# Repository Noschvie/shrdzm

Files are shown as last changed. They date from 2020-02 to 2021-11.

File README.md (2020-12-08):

SHRDZM   

## SHRDZM is intended to become an end-to-end integration platform.
It provides wiring digrams, source code and working examples.
Also plug-ins for most commonly used home automation solutions will be collected.

To build cheap integrations of many kind of sensors and/or actors into your own automation solution with the focus on energy efficiancy (battery operated devices) and simpleness.

Take a look on the [Wiki](https://github.com/saghonfly/shrdzm/wiki)

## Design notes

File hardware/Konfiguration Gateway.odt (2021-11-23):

Konfiguration Gateway:

1. Resetten bei gleichzeitig gedrücktem Pairing-Knopf

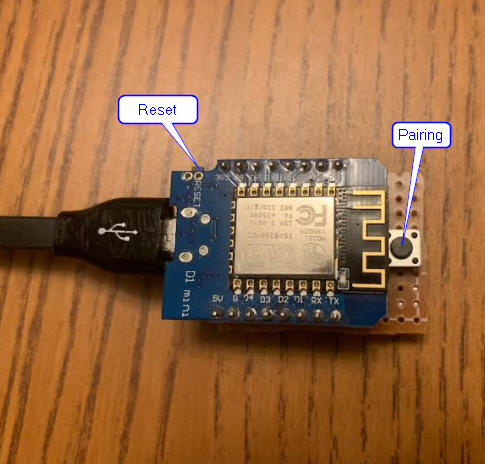
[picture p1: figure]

2. Wenn die LED vom Wemos blinkt, Pairing Knopf loslassen. Das Gateway befindet sich jetzt im AP Modus.
3. Mit dem AP verbinden

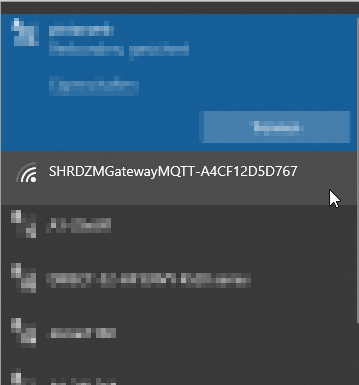
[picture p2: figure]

4. Mit dem Browser auf 192.168.4.1 gehen

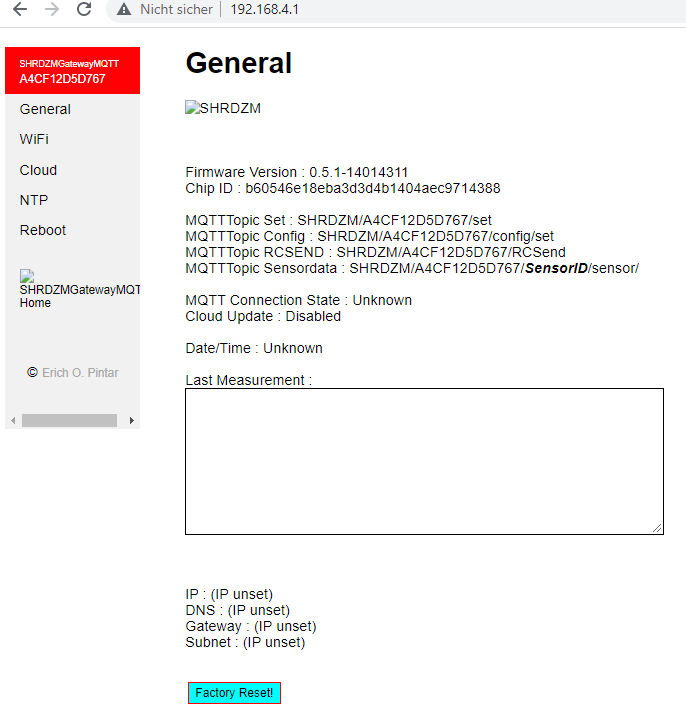
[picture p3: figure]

5. Auf WiFi Einstellungen gehen und die Zugangsdaten vom Router eingeben.

Zum Testen die MQTT Einstellungen auf test.msoquitto.org lassen. Für den produktiven Betrieb wird aber dringend ein eigener MQTT Broker empfohlen!

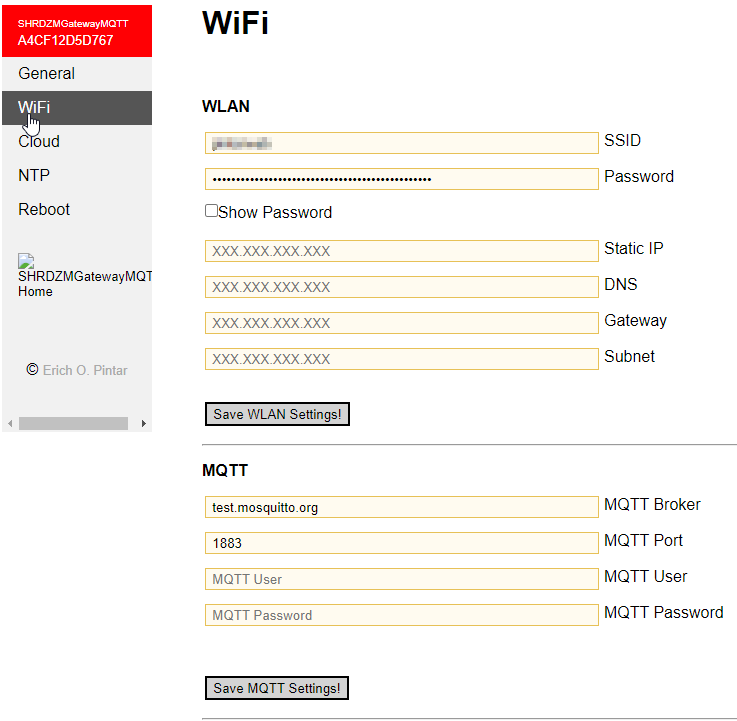
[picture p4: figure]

6. Gateway booten. Dieses sollte sich nun in das eigene WLAN eingebucht haben bzw. eine eigene IP Adresse von diesem bekommen haben über die das Gateway wieder erreichbar sein sollte.
7. Einen MQTT Client starten. Ich empfehle MQTT.fx (nicht die aktuellste Version, die ist mittlerweile kostenpflichtig, eine Ältere tuts auch)

Einstellungen für test.mosquitto.org

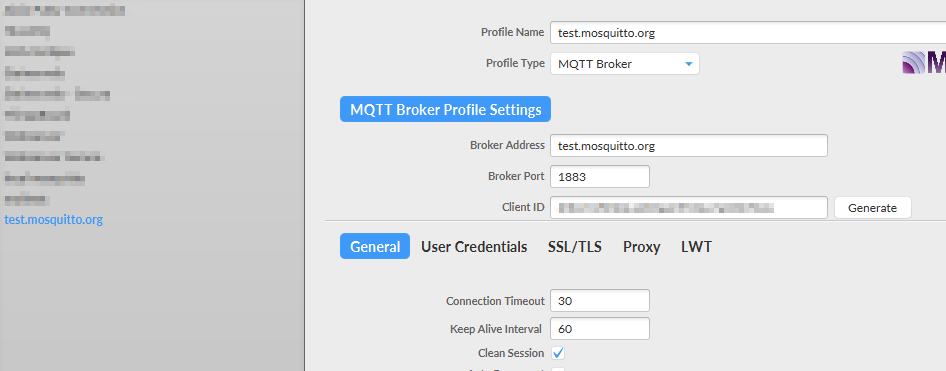
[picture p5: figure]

8. Mit test.mosquitto.org verbinden und für ‚SHRDZM/#‘ Nachrichten registrieren

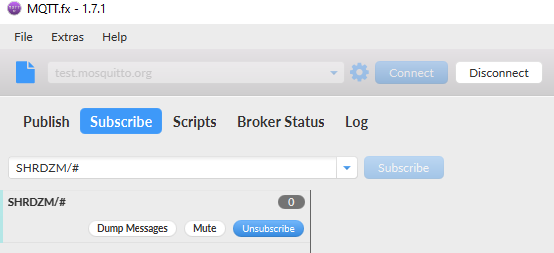
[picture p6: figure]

9. Gateway booten. Sobald das Gateway gebootet hat, sollten schon ein paar Nachrichten sichtbar sein.

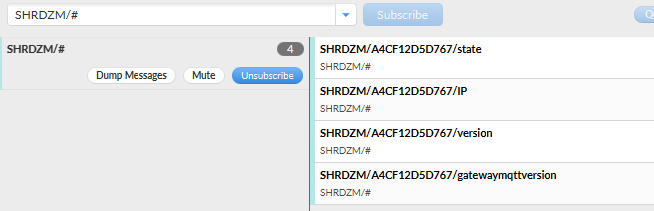
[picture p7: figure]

10. Auf den Reiter Publish gehen und den eigenen Cipherkey (32 Zeichen) an das Gateway schicken

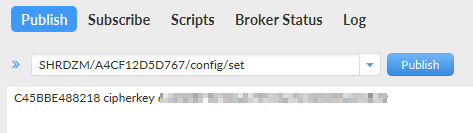
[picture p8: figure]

^

11. Der Cipherkey wird übernommen sobald der Sensor aufwacht (kann bis zu 2 Minuten dauern) bzw. der Accu neu eingelegt wird.
12. Sensor beim SmartMeter anstecken. Ab jetzt sollten alle 2 Minuten decodierte Messwerte ankommen

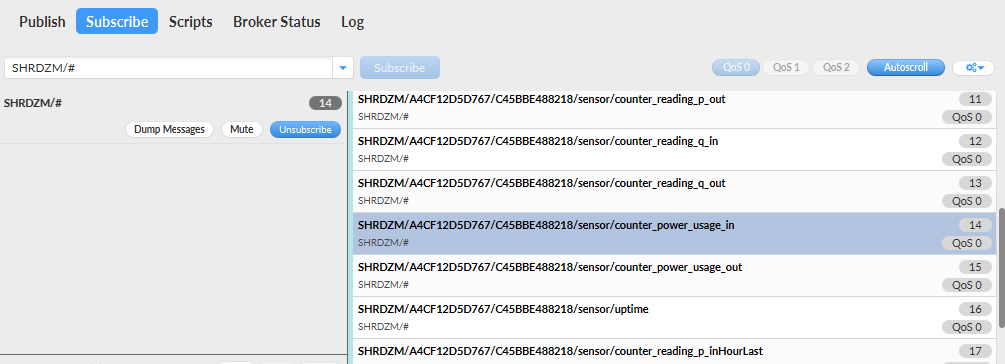
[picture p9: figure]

Die Werte für uptime, counter_reading_p_inHourLast und counter_reading_p_inDayLast können bei der batteriebetriebenen Variante ignoriert werden. Diese stimmen nur bei Sensoren die permanent mit Strom versorgt werden.

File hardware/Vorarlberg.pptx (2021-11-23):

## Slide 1

- KSMWest H1 interface

- Electricity Metering Solutions

- KSMWest

- 08.05.2018

## Overview M-Bus - Physical Layer

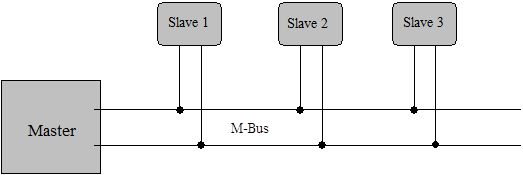
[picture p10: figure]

The M-Bus consists of
- The master,
- A number of slaves
- A two-wire connecting cable

Master to Slave => The transfer of bits from master to slave is accomplished by means of voltage level shifts.
- A logical "1" (Mark) corresponds to a nominal voltage of +36 V
- A logical "0" (Space) reduces the bus voltage by 12 V to a nominal +24 V
Slave to Master => The transfer of bits from slave to master slave is accomplished by means of modulating the current consumption of the slave.
- A logical "1" (Mark) is represented by a constant current of up to 1.5 mA,
- A logical "0" (Space) is represented by an increased current drain requirement by the slave of additional 11-20 mA.

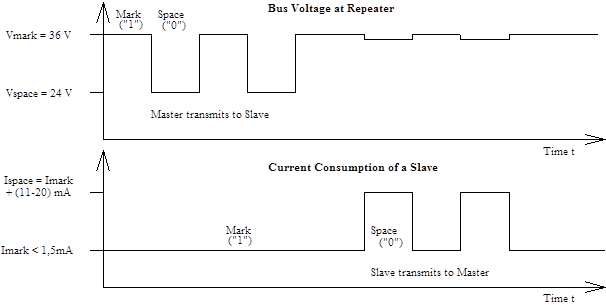
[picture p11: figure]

## Overview M-Bus - Data Link Layer

Telegram format - FT 1.2 according to IEC 870-5:
=> The format class FT 1.2 specifies three different telegram formats, which can be recognized by means of special start characters
Single Character
This format consists of a single character, namely the E5h (decimal 229), and serves to acknowledge receipt of transmissions.
Short Frame
This format with a fixed length begins with the start character 10h, and besides the C and A fields includes the check sum (this is made up from the two last mentioned characters), and the stop character 16h.
Long Frame
With the long frame, after the start character 68h, the length field (L field) is first transmitted twice, followed by the start character once again. After this, there follow the function field (C field), the address field (A field) and the control information field (CI field). The L field gives the quantity of the user data inputs plus 3 (for C,A,CI). After the user data inputs, the check sum is transmitted, which is built up over the same area as the length field, and in conclusion the stop character 16h is transmitted.
Control Frame
The control sentence conforms to the long sentence without user data, with an L field from the contents of 3. The check sum is calculated at this point from the fields C, A and CI.

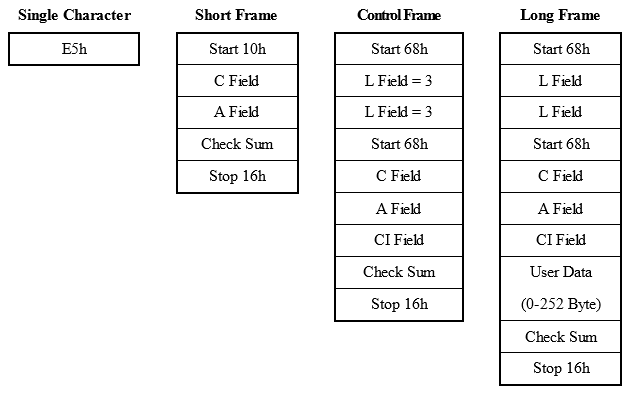
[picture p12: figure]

## Overview M-Bus - Data Link Layer

C Field (Control Field)
The control field specifies the direction of data flow, and is responsible for various additional tasks in both the calling and replying directions.
A Field (Address Field)
The address field serves to address the recipient in the calling direction, and to identify the sender of information in the receiving direction. The size of this field is one Byte, and can therefore take values from 0 to 255.
- Address 0: indicates an unconfigured slave
- Address 1-250: can be allocated to the individual slaves
- Address 251-252: reserved
- Address 253: Network Layer addressing used instead of Data Link Layer addressing
- Address 254: broadcast - all slaves reply with their own addresses
- Address 255: broadcast - none of the slaves reply
CI Field (control information field)
The control information field is already a part of the Application Layer, The control information allows the implementation of a variety of actions in the master or the slaves.
Check Sum
The Check Sum is calculated from the arithmetical sum of the data mentioned above, without taking carry digits into account.

Coding of the Control Field

Control Codes of the M-Bus Protocol (F : FCB-Bit, A : ACD-Bit, D : DFC-Bit)

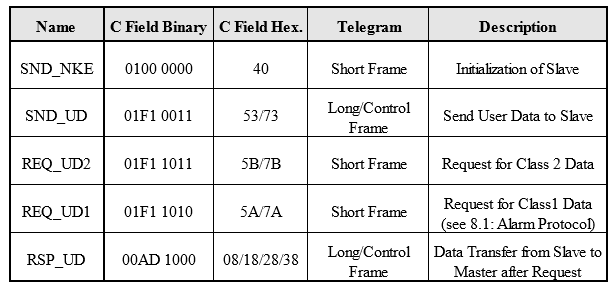
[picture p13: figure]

## Overview M-Bus – Transport Layer

CI field values

The M-Bus transport layer allows several application layers to co-exist over the M-Bus lower layers.
These may be:
- the M-Bus dedicated AL
- the DLMS/COSEM AL
- some other AL that may be specified in the future.
The AL used is selected by the Control Information (CI) field of the M-Bus frame.

CI | Application
00h-1Fh | DLMS/COSEM M-Bus based TL No M-Bus Data Header is present
20h-4Fh | reserved for DLMS-based applications
50h | application reset
51h | data send (master to slave)
52h | selection of slaves
53h | reserved
54h-58h | reserved for DLMS-based applications
55h-5Bh | reserved
5Ch | synchronise action
60h | DLMS/COSEM M-Bus based TL Long M-Bus Data Header present, direction master to slave
61h | DLMS/COSEM M-Bus based TL Short M-Bus Data Header present, direction master to slave
62h-6Fh | reserved
70h | slave to master: report of application errors
71h | slave to master: report of alarms
72h | slave to master: 12 byte header followed by variable format data
73h-77h | reserved
78h | slave to master: Variable data format response without header
79h | reserved
7Ah | slave to master: 4 byte header followed by Variable data format response
7Bh | reserved
7Ch | DLMS/COSEM M-Bus based TL Long M-Bus Data Header present, direction slave to master
7Dh | DLMS/COSEM M-Bus based TL Short M-Bus Data Header present, direction slave to master
7Eh-80h | reserved
81h | Reserved for a future CEN-TC294- Radio relaying and application Layer
82h | Reserved for a future CENELEC-TC205 network/application Layer
82h-8Fh | reserved
90h-97h | manufacturer specific (obsolete)
A0h-AFh | manufacturer specific
B0-B7h | manufacturer specific
B8h | set baudrate to 300 baud
B9h | set baudrate to 600 baud
BAh | set baudrate to 1200 baud
BBh | set baudrate to 2400 baud
BCh | set baudrate to 4800 baud
BDh | set baudrate to 9600 baud
BEh | set baudrate to 19200 baud
BFh | set baudrate to 38400 baud
C0h-FFh | reserved

## DLMS/COSEM M-Bus transport layer

DLMS/COSEM AL based CI values

CI without M-Bus Data Header

The values CITL = 0x00…0x1F indicate that no M-Bus Data Header is present. In this case, the TL can provide segmentation and reassembly
- Bit 4 (FIN) indicates that the Data field of the TPDU carries either one part of an xDLMS APDU or the complete APDU.
- Bits 3 to 0 are used for sequence numbering. The rollover of the sequence numbers is permitted, meaning that when the sequence number reaches the value 1111 and there are segments remaining to be sent, the next segment sequence number will take the value 0000.

## Example M-Bus frame

## Example M-Bus frame

DLMS/COSEM APDU

DLMS/COSEM APDU (decrypted payload)

data-notification
long-invoke-id-and-priority
invoke-id: 366
not-self-descriptive
processing-option: continue on error
service-class: unconfirmed
priority: normal
date-time
07 E0 09 09 05 11 3A 00 00 FF C4 80 '......:.....'
2016/09/09 17:58:00
Day of Week: 5
Deviation to GMT: -60 minutes
Clock Status: 80
notification-body
data
structure with 7 elements
struct-element-0
octet-string:
07 E0 09 09 05 11 3A 00 00 00 00 80 '......:.....'
struct-element-1
octet-string:
01 00 01 08 00 FF '......'
struct-element-2
double-long-unsigned: 0
struct-element-3
structure with 2 elements
struct-element-0
integer: 0
struct-element-1
enum: 30
struct-element-4
octet-string:
01 00 03 08 00 FF '......'
struct-element-5
double-long-unsigned: 0
struct-element-6
structure with 2 elements
struct-element-0
integer: 0
struct-element-1
enum: 32

general-glo-ciphering
45 4C 53 65 70 00 00 01 'ELSep...'
system-title: 454c536570000001
ciphered-service:
length: 77
security-control-byte
security-suite-id: 0
encryption
key-set: unicast
frame-counter: 144
apdu:
E2 A3 30 F9 B7 E0 D6 8C 09 37 5A A1 B1 F8 F3 A7 '..0......7Z.....'
DF 14 B7 79 0E 14 D1 55 6A B8 75 B1 49 E6 84 7D '...y...Uj.u.I..}'
11 93 6D B5 19 1D D0 F4 89 BA 76 8C 2D BB 68 F6 '..m.......v.-.h.'
B0 01 E3 04 C2 1F EA 14 7E 0B 2E 2C A1 B9 1D 57 '........~..,...W'
4D F4 F7 F5 82 CE BE 92 'M.......'

## Companion Standard – H1 interface

## Thank you!

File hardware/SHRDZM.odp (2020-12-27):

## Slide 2

SHRDZMDevice

SHRDZMDevice

SHRDZMDevice

SHRDZMDevice

SHRDZMDevice

SHRDZMGateway

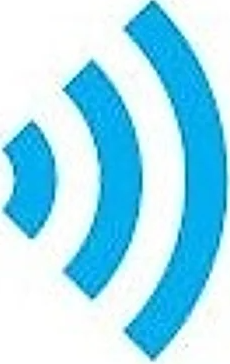
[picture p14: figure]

SHRDZMGatewayMQTT

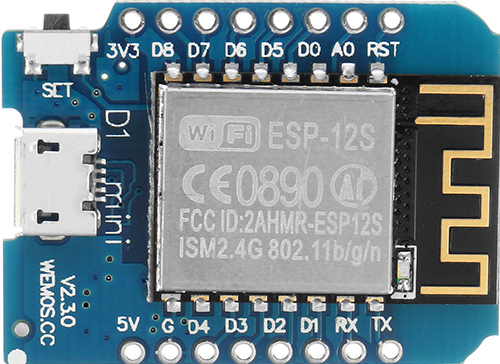
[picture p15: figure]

Home Automation
Solution

WLAN

SERIAL

ESPNow

Sensor
Actor

Sensor
Actor

Sensor
Actor

Sensor
Actor

Sensor
Actor

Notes: Copyright © Infineon Technologies AG 2020. All rights reserved. restricted 2020-05-25 <Nummer>

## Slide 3

SHRDZMDevice

SHRDZMDevice

SHRDZMDevice

SHRDZMDevice

SHRDZMDevice

SHRDZMGateway

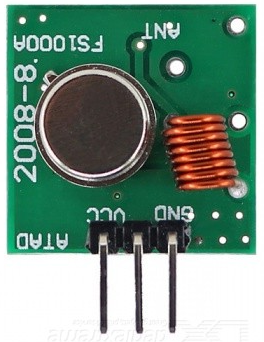
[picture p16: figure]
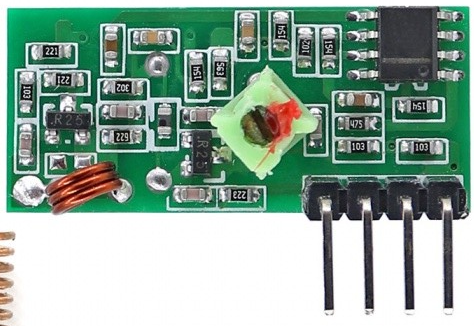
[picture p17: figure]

433MHz Transmitter/Receiver

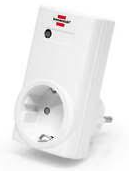
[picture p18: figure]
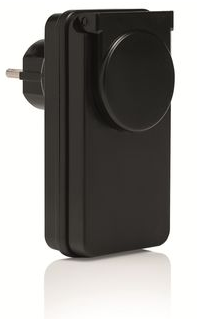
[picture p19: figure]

SHRDZMGatewayMQTT

Home Automation
Solution

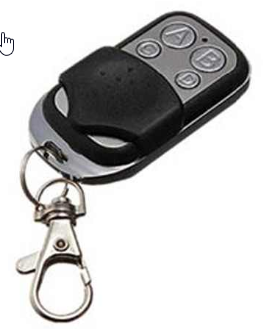
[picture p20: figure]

WLAN

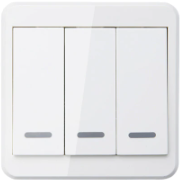
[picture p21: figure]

SERIAL

ESPNow

Sensor
Actor

Sensor
Actor

Sensor
Actor

Sensor
Actor

Sensor
Actor

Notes: Copyright © Infineon Technologies AG 2020. All rights reserved. restricted 2020-05-25 <Nummer>

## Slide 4

SHRDZMDevice

SHRDZMDevice

SHRDZMDevice

SHRDZMDevice

SHRDZMDevice

SHRDZMGateway

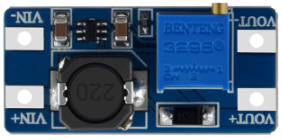
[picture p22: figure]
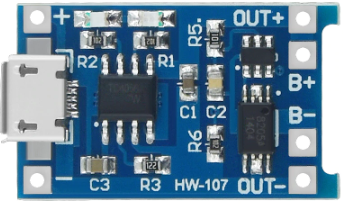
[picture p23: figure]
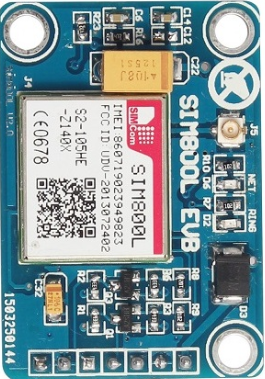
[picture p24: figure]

Home Automation
Solution

GSM

3.7V

5V

SERIAL

5V - USB

3.7V

3.7V

ESPNow

Sensor
Actor

Sensor
Actor

Sensor
Actor

Sensor
Actor

Sensor
Actor

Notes: Copyright © Infineon Technologies AG 2020. All rights reserved. restricted 2020-05-25 <Nummer>

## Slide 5

SHRDZMDevice

SHRDZMDevice

SHRDZMDevice

SHRDZMDevice

SHRDZMDevice

SHRDZMGatewayMobile


Home Automation
Solution

GSM

SERIAL

ESPNow

Sensor
Actor

Sensor
Actor

Sensor
Actor

Sensor
Actor

Sensor
Actor

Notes: Copyright © Infineon Technologies AG 2020. All rights reserved. restricted 2020-05-25 <Nummer>

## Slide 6

5 Volt

SHRDZMDevice

Home Automation
Solution

WLAN

Sensor
Actor

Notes: Copyright © Infineon Technologies AG 2020. All rights reserved. restricted 2020-05-25 <Nummer>


5 Volt/ >= 500mA

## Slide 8


Replace existing capacitor with 2200uF

5 Volt - USB


+5V

Optional


Solar Panel
~5 Watt

+

AccessPoint
Trigger

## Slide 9

5 Volt - USB


Optional

Solar Panel
~5 Watt

AccessPoint
Trigger

+

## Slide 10

S

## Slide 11

Boot

Pairing Pin

Closed

Normal Mode

> 5 sec

Pairing Mode

0 sec

Pairing Pin

Closed

> 3 sec, < 10 sec

Configuration AP Mode

Pairing Pin

Closed

Factory Reset

> 10 sec

FHEM Server


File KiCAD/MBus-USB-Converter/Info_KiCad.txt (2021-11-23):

Application: kicad
Version: (5.0.1)-4, release build
Libraries:
    wxWidgets 3.0.4
    libcurl/7.61.1 OpenSSL/1.1.1 (WinSSL) zlib/1.2.11 brotli/1.0.6 libidn2/2.0.5 libpsl/0.20.2 (+libidn2/2.0.5) nghttp2/1.34.0
Platform: Windows 7 (build 7601, Service Pack 1), 64-bit edition, 64 bit, Little endian, wxMSW

Build Info:
    wxWidgets: 3.0.4 (wchar_t,wx containers,compatible with 2.8)
    Boost: 1.68.0
    OpenCASCADE Community Edition: 6.9.1
    Curl: 7.61.1
    Compiler: GCC 7.3.0 with C++ ABI 1011

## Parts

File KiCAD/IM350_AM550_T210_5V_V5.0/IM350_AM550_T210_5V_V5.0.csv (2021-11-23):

Comment | Designator | Footprint | LCSC
22uF | C1,C2,C4 | Capacitor_SMD:C_1206_3216Metric_Pad1.33x1.80mm_HandSolder
0.1uF | C3 | Capacitor_SMD:C_1206_3216Metric_Pad1.33x1.80mm_HandSolder
0.22uF | C5 | Capacitor_SMD:C_1206_3216Metric_Pad1.33x1.80mm_HandSolder
USB_B_Micro_Power | J1 | SHRDZM:USB_Micro-B_Power
RJ12 | J2 | ErichCollection:RJ12_Amphenol_54601
BC847 | Q1 | Package_TO_SOT_SMD:SOT-23
P3 | R1 | Resistor_SMD:R_0201_0603Metric_Pad0.64x0.40mm_HandSolder
1.5k | R5,R10 | Resistor_SMD:R_0805_2012Metric_Pad1.20x1.40mm_HandSolder
220 | R11,R12 | Resistor_SMD:R_0805_2012Metric_Pad1.20x1.40mm_HandSolder
0 | R13 | Resistor_SMD:R_0201_0603Metric_Pad0.64x0.40mm_HandSolder
30k | R15 | Resistor_SMD:R_0805_2012Metric_Pad1.20x1.40mm_HandSolder
M_RX | R18 | Resistor_SMD:R_0201_0603Metric_Pad0.64x0.40mm_HandSolder
P4 | R2 | Resistor_SMD:R_0201_0603Metric_Pad0.64x0.40mm_HandSolder
2.2k | R3 | Resistor_SMD:R_0805_2012Metric_Pad1.20x1.40mm_HandSolder
100k | R4,R14 | Resistor_SMD:R_0805_2012Metric_Pad1.20x1.40mm_HandSolder
M_TX | R6 | Resistor_SMD:R_0201_0603Metric_Pad0.64x0.40mm_HandSolder
P1_TX | R7 | Resistor_SMD:R_0201_0603Metric_Pad0.64x0.40mm_HandSolder
10k | R8,R9,R16,R17 | Resistor_SMD:R_0805_2012Metric_Pad1.20x1.40mm_HandSolder
SW_Push | SW1 | Button_Switch_SMD:SW_SPST_CK_RS282G05A3
AMS1117-3.3 | U1 | Package_TO_SOT_SMD:SOT-223-3_TabPin2
ESP-12F | U2 | RF_Module:ESP-12E
TSS721ADR | U3 | TSS721ADR:SOIC127P600X175-16N
EL357NC | U4,U5 | Package_SO:SOIC-4_4.55x2.6mm_P1.27mm

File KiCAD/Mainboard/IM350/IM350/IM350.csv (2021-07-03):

Comment | Designator | Footprint | LCSC
22uF | C1,C2 | 603 | C59461
USB_B_Micro | J1 | Connector_USB:USB_Micro-B_GCT_USB3076-30-A
Conn_02x03_Odd_Even | J2 | Connector_PinHeader_2.54mm:PinHeader_2x03_P2.54mm_Horizontal
BC547 | Q1 | Package_TO_SOT_THT:TO-92_Inline_Horizontal1
10k | R1,R2,R3 | 402 | C25744
SW_Push | SW1 | Button_Switch_THT:SW_PUSH_6mm
AMS1117-3.3 | U1 | SOT-223 | C6186
ESP-12F | U2 | RF_Module:ESP-12E

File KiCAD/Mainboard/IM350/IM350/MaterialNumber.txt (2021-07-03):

10kOhm 		0402 		C25744
AMS1117 	SOT-223 	C6186
22uF		0603		C59461

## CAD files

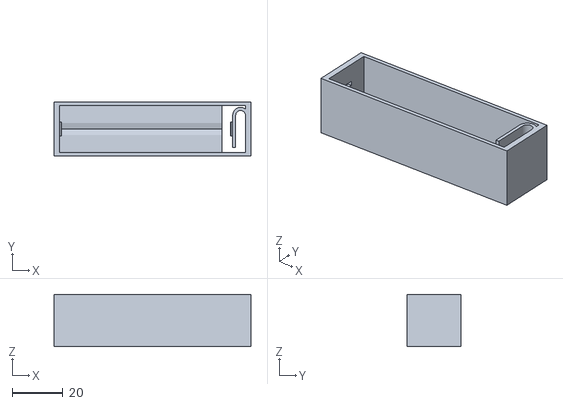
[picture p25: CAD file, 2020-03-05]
3d/18650/Bottom.stl
77.4 x 21.4 x 20.6

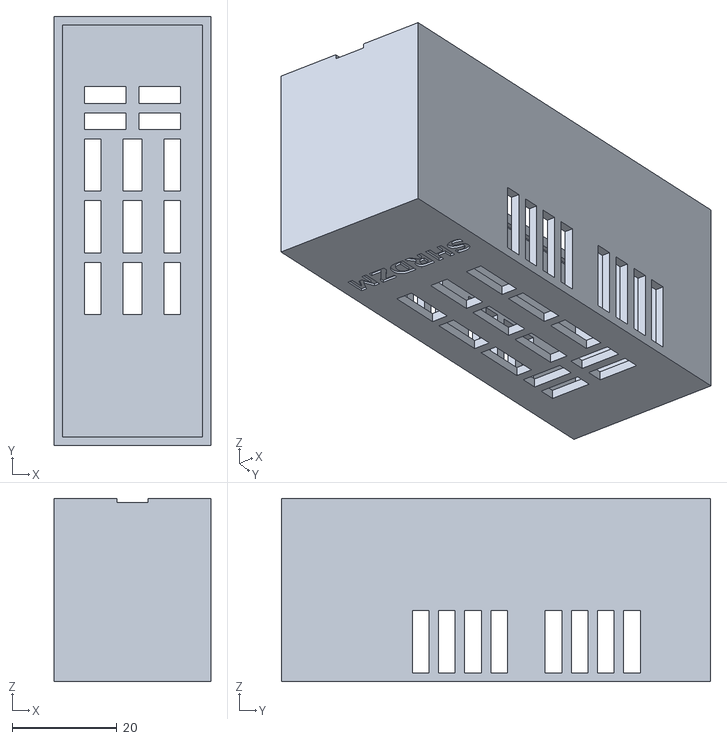
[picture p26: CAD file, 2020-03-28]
3d/Case2.stl
30.0 x 82.0 x 35.0

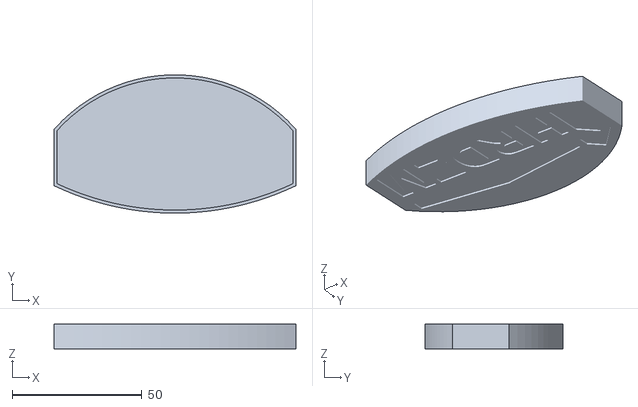
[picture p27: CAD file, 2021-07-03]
3d/Watersensor/HolderTop_2.stl
93.4 x 53.3 x 9.50

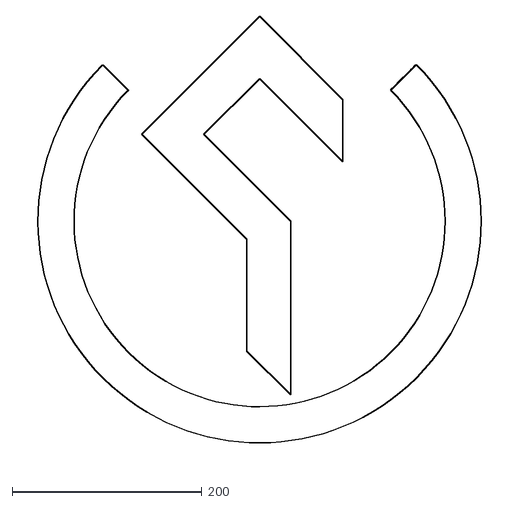
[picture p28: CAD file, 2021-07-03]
hardware/Logo_min.dxf
512.7 x 472.1

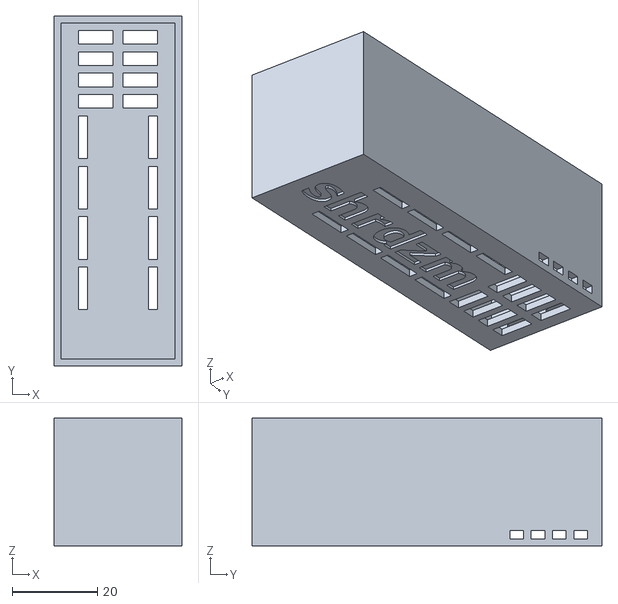
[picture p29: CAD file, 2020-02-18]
3d/Case1.stl
30.0 x 82.0 x 30.0

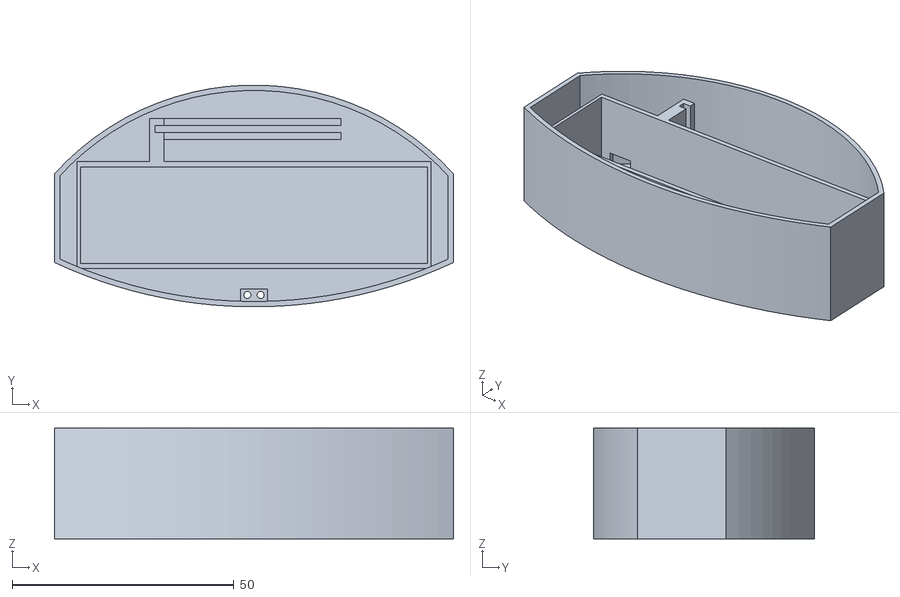
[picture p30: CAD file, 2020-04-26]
3d/Watersensor/Holder_1.stl
90.0 x 49.9 x 25.0

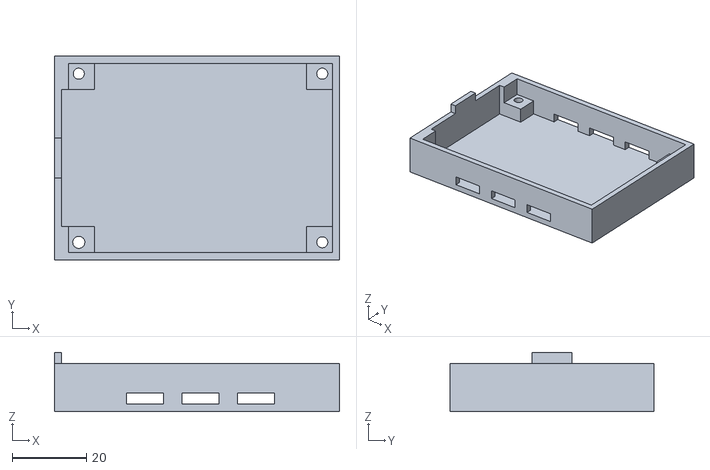
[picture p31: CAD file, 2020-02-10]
hardware/ESPWLANGatewayBottom.stl
76.9 x 55.0 x 16.0

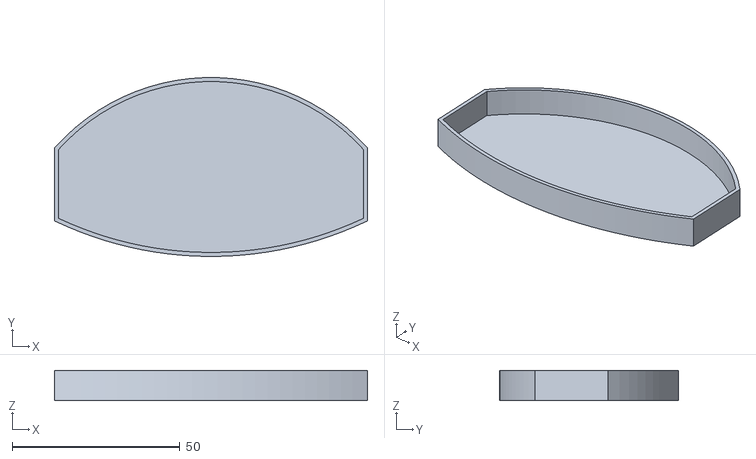
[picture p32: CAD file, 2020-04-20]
3d/Watersensor/HolderTop_1.stl
93.4 x 53.3 x 9.00

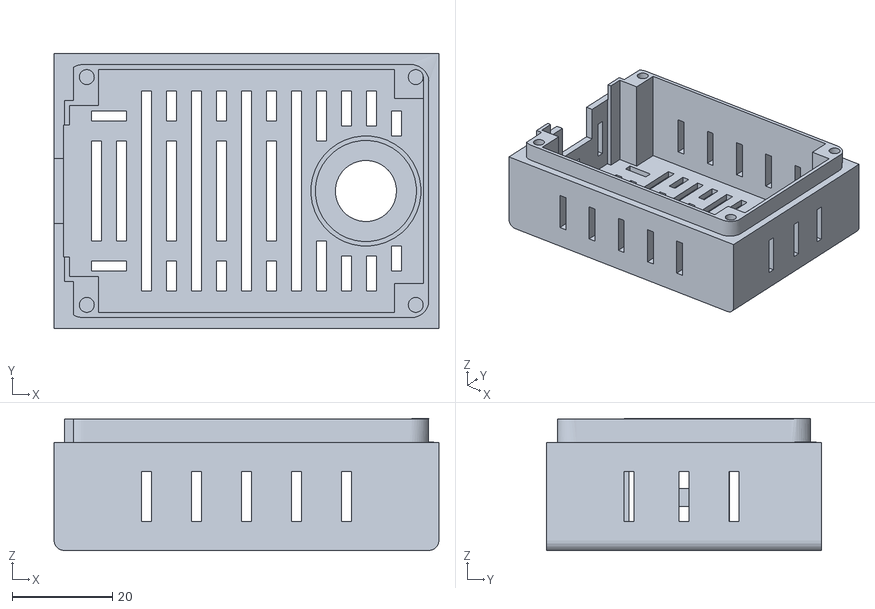
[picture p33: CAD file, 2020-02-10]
hardware/ESPWLANGatewayTop.stl
76.9 x 55.0 x 26.4

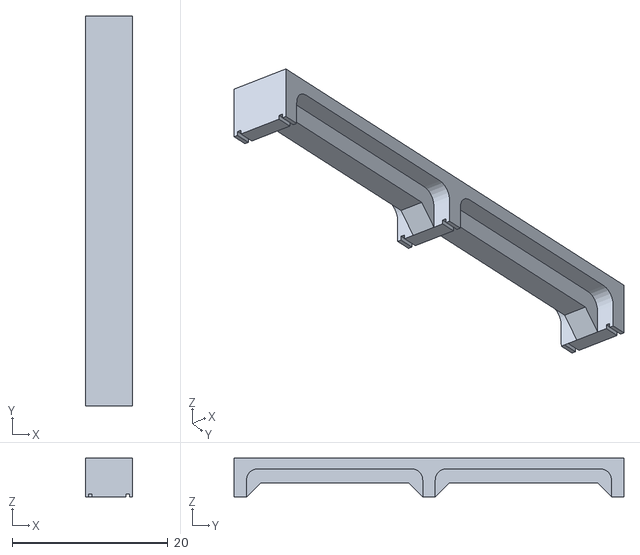
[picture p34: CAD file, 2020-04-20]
3d/Watersensor/Holder.stl
6.00 x 50.0 x 5.00

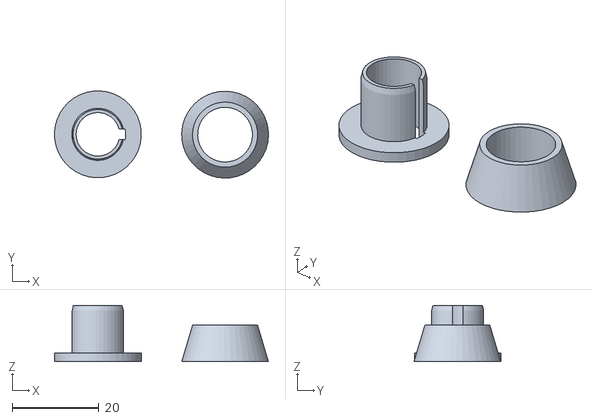
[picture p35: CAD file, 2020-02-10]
hardware/ESPWLANGatewayAntennaHolder.stl
49.3 x 20.1 x 13.0

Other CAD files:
3d/18650/Bottom.skp
3d/18650/Bottom1.skp
3d/18650/Bottom2.skp
3d/Case1.skp
3d/Case2-0.skp
3d/Case2.skp
3d/Watersensor/Holder.skp
3d/Watersensor/HolderTop_1.skp
3d/Watersensor/HolderTop_2.skp
3d/Watersensor/Holder_1-0.skp
3d/Watersensor/Holder_1.skp

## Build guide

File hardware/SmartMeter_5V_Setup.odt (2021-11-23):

SHRDZMDevice für SmartMeter

Einstellungen

1) Pairing-Knopf gedrückt halten und 5V Stromversorgung (mindestens 1A) anstecken.

2) Paining-Knopf loslassen. Die blaue LED blinkt ca. alle halbe Sekunde auf. Das Device befindet sich nun im Pairing-Modus mit einem optionalen Gateway (für Batteriebetrieb, hier nicht der Fall!)
3) Mindesten 5 Sekunden warten und Pairing-Knopf erneut für ca. 5 Sekunden gedrückt halten. Loslassen sobald die blaue LED schnell zu blinken beginnt. Nun befindet sich das Device im AccessPoint Modus.

4) Sobald sich das Device im AP Modus befindet, kann mit diesem eine WLAN Verbindung aufgebaut werden:

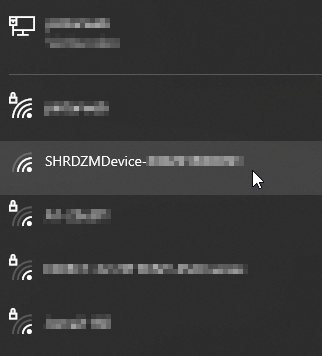
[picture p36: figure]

5) Sobald die Verbindung aufgebaut ist, kann mittels Browser über die IP-Adresse 192.168.4.1 darauf zugegriffen werden:

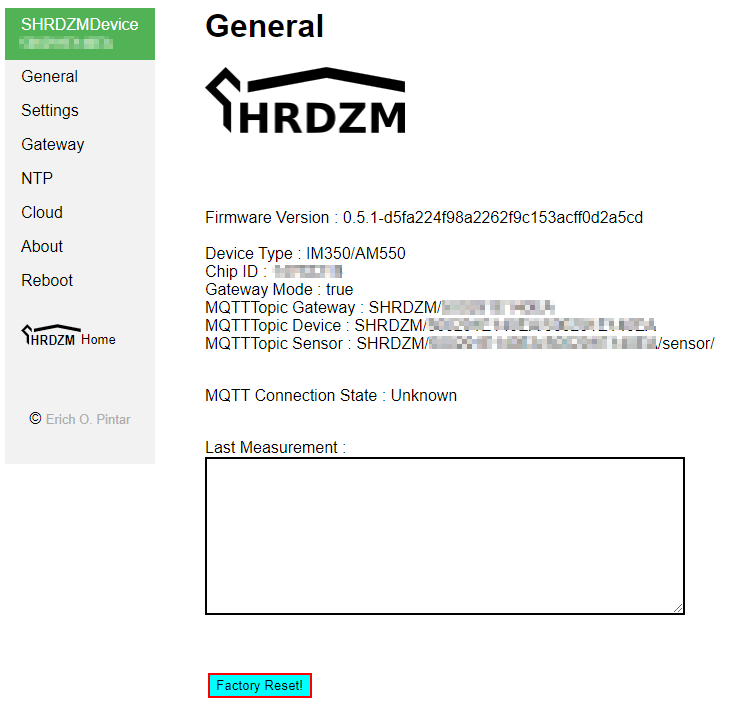
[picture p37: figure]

6) Auf Settings wechseln und den 32 Zeichen langen persönlichen Cipherkey vom Stromnetzbetreiber eintragen. Die anderen Einstellungen nicht ändern.

7) Save Configuration! drücken.

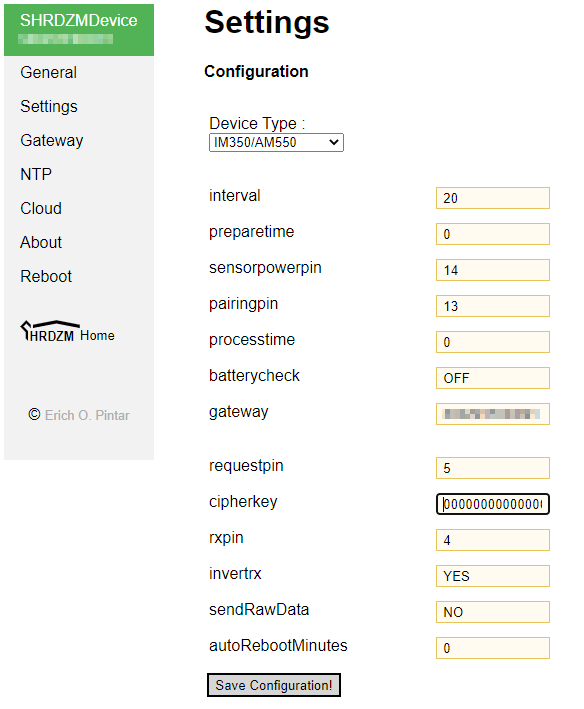
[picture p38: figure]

8) Auf Gateway Einstellungen wechseln. Hier die WiFi SSID und das Passwort eintragen.

8a) [optional] Bei Benutzung einer statischen IP, könnte auch diese eingetragen werden. Im Normalfall leer lassen da diese vom Router vergeben wird.

9) MQTT Server, Port und eventuell User und Passwort eintragen. Wenn kein User/Passwort verwendet wird, diesen leer lassen.

9a) [optional] Sollte keine Integration in die eigene Hausautomatisierung gewünscht sein, kann das Häkchen bei ‚MQTT Enable‘ entfernt werden. In solch einem Fall werden dann keine Daten an den MQTT Broker geschickt. (sinnvoll, wenn nur Cloud/Alexa Anbindung gewünscht)

10) Save Configuration! drücken.

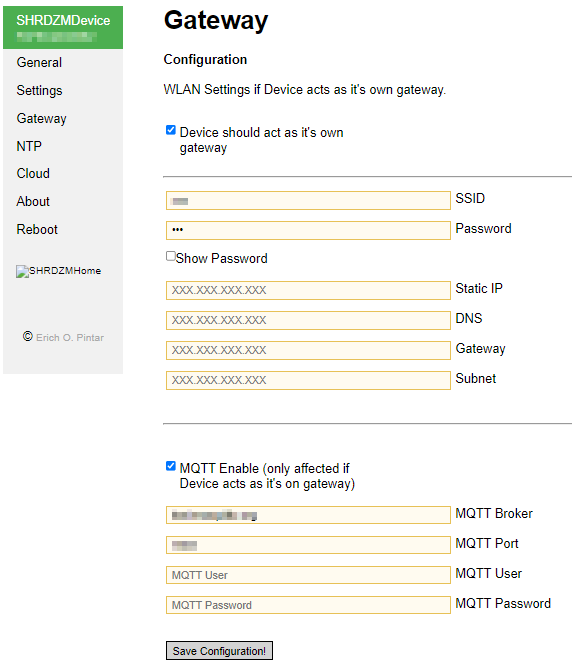
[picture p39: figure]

11) Device booten.

12) Nach dem Rebooten sollte sich das Device im WLAN einwählen und von dort eine eigene IP – Adresse bekommen. Über diese IP-Adresse ist das Device dann wieder mittels Browser erreichbar und Einstellungen können verändert werden.

13) Nach dem Verbinden mit dem SmartMeter sollten die Messwerte über die auf der Übersichtsseite beschriebenen MQTT Subjects angezeigt werden.

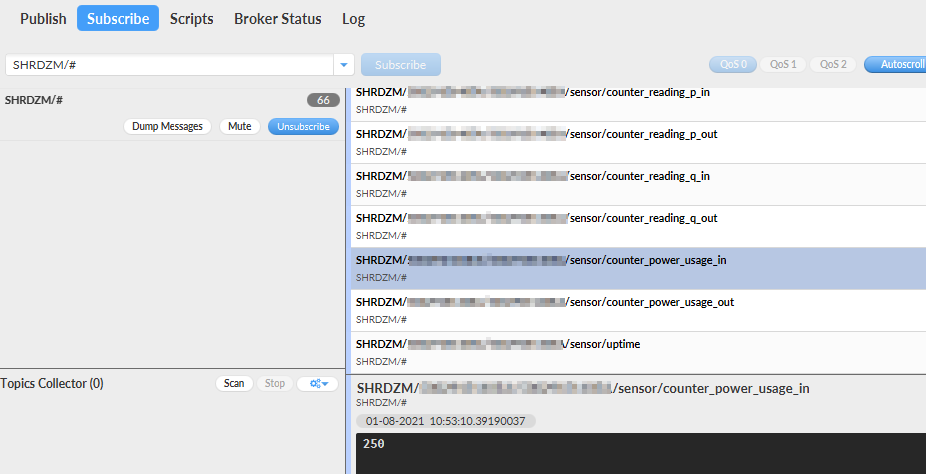
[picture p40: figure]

Optional

Das Device hat eine optionale Cloud-Anbindung die sich jedoch noch in Entwicklung befindet.

Derzeit implementiert ist nur die Alexa Anbindung. (Ein Änderung der Einstellung wirkt nicht wenn sich das Device beim Konfigurieren im AP Modus befindet!)

14) Auf Cloud Einstellungen wechseln.

15) „Cloud Enabled“ Checkbox anklicken.

16) ‚Save Cloud Settings“ drücken.

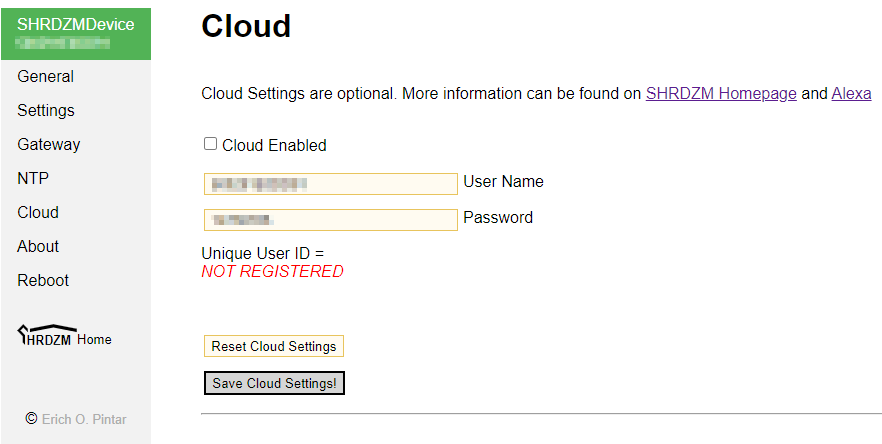
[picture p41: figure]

Der abgebildete User Name und das Passwort ist beim Alexa Account Linking zu verwenden.

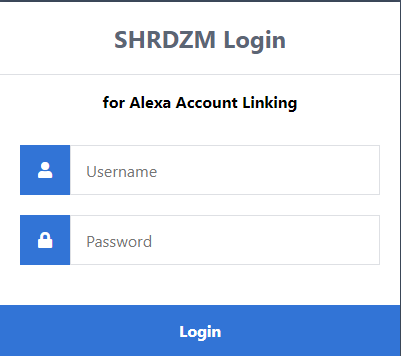
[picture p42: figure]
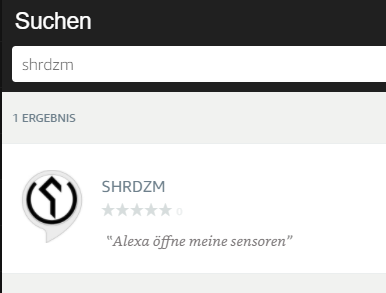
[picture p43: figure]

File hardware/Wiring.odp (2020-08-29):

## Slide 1

10 kOhm

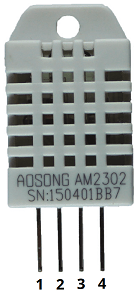
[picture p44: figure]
DHT22 Temperature and Humidity Sensor using Arduino IDE

3.3 V

+

Pairing

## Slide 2

5V USB

10 kOhm

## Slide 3

18650

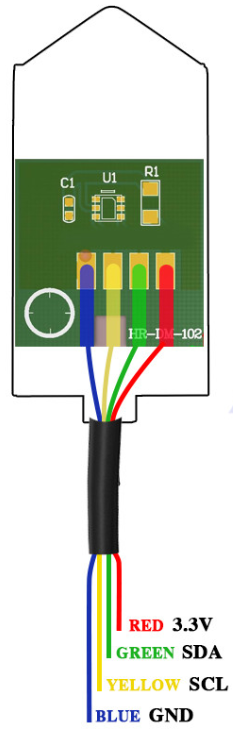
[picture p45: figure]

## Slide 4

5V USB

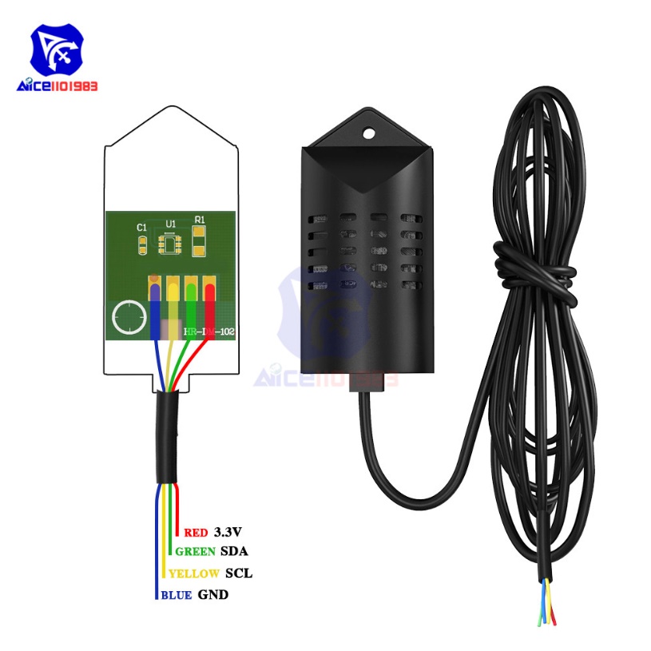
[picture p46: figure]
X12962解说图

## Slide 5

3.3 V

Pairing

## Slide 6

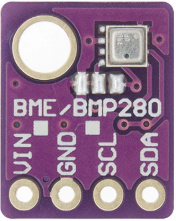
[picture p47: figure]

3.3 V

Pairing

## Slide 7

5V USB

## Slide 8

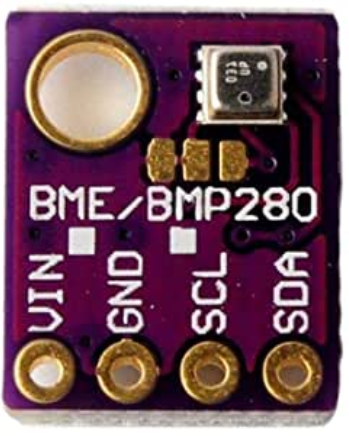
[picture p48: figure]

3.3 V

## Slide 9

5V USB

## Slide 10

GY-302

3.3 V

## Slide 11

5V USB

GY-302

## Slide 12

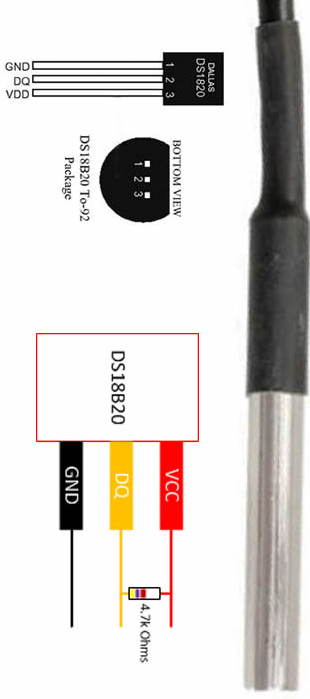
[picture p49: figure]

DS18B20

3.3 V

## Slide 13

5V USB

DS18B20

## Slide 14

18650

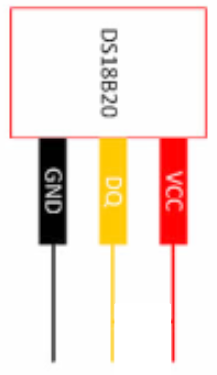
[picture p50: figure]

4,7 kΩ

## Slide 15

1 MOhm

100 nF

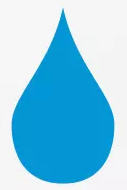
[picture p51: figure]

+

3.3 V

Pairing

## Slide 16

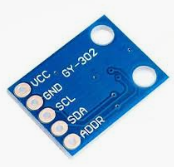
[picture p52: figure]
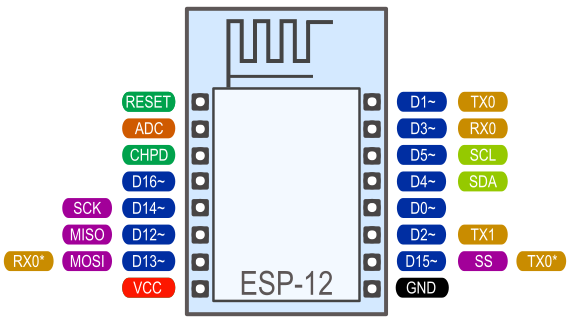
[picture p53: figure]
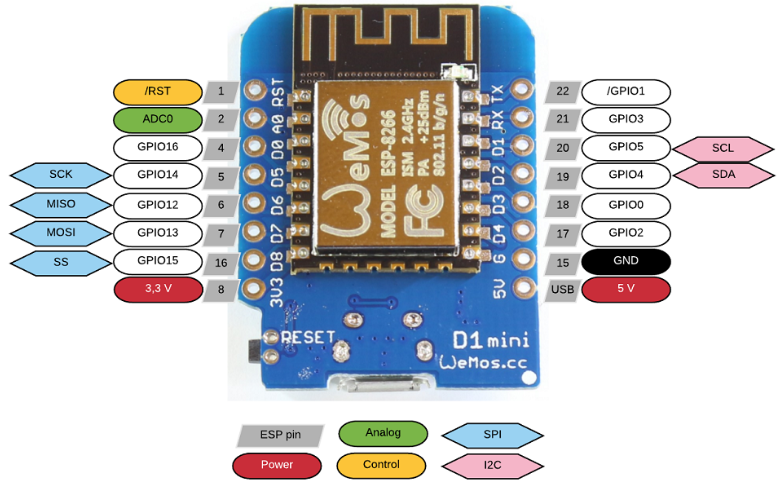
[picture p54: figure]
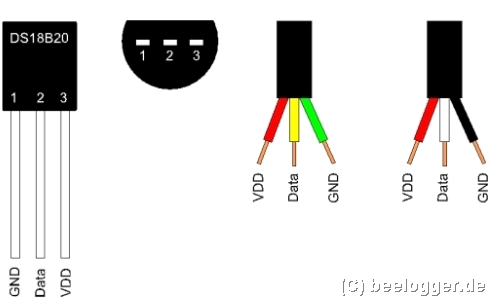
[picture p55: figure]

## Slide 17

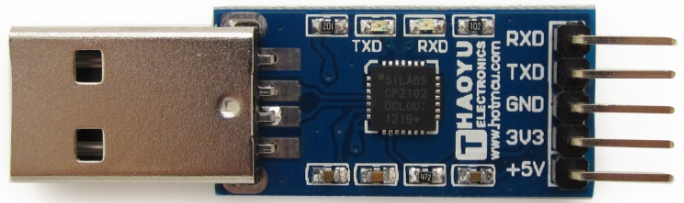
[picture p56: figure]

5V USB

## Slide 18

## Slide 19

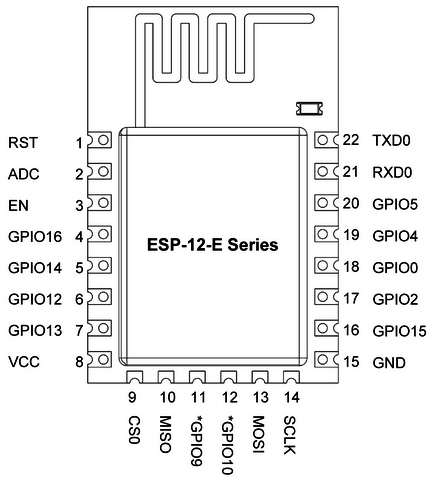
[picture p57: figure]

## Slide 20

R2

22 kOhm

R1

4.7 kOhm

R3

10 kOhm

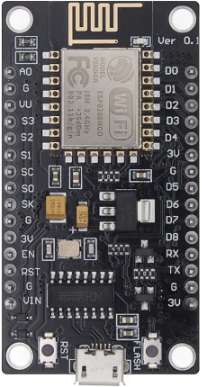
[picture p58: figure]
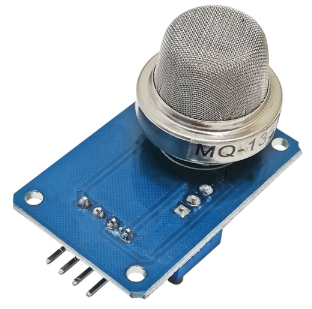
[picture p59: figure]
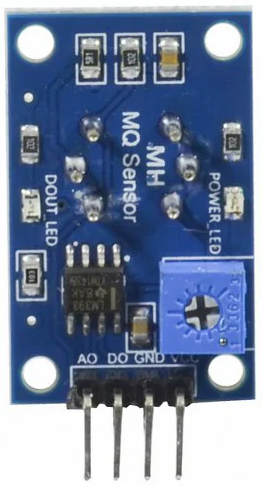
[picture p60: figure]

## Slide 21

R2

22 kOhm

R1

4.7 kOhm

R3

10 kOhm

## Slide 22

Vin

Vout

R3
10 kOhm

R1
10 kOhm

R2
3.3 kOhm

18650

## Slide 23

R3
10 kOhm

IRLZ44N

SDS011

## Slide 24

R3
10 kOhm

IRLZ44N

SDS011

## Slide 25

10kOhm

18650

100kO

330kO

5 Watt

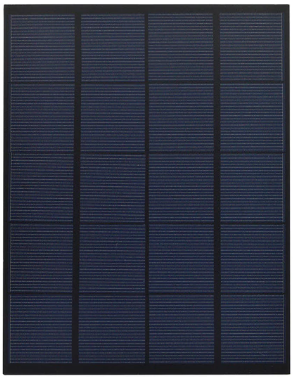
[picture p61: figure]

IRLZ44N

SDS011

+

DC/DC Step Up

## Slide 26

18650

100kO

330kO

5 Watt

SDS011

+

DC/DC Step Up

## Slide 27

18650

5 Watt

SDS011

+

DC/DC Step Up

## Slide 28

SDS011

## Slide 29

R1
330 kOhm

18650

R2
100 kOhm

R1
330 kOhm

18650

R2
1 MOhm

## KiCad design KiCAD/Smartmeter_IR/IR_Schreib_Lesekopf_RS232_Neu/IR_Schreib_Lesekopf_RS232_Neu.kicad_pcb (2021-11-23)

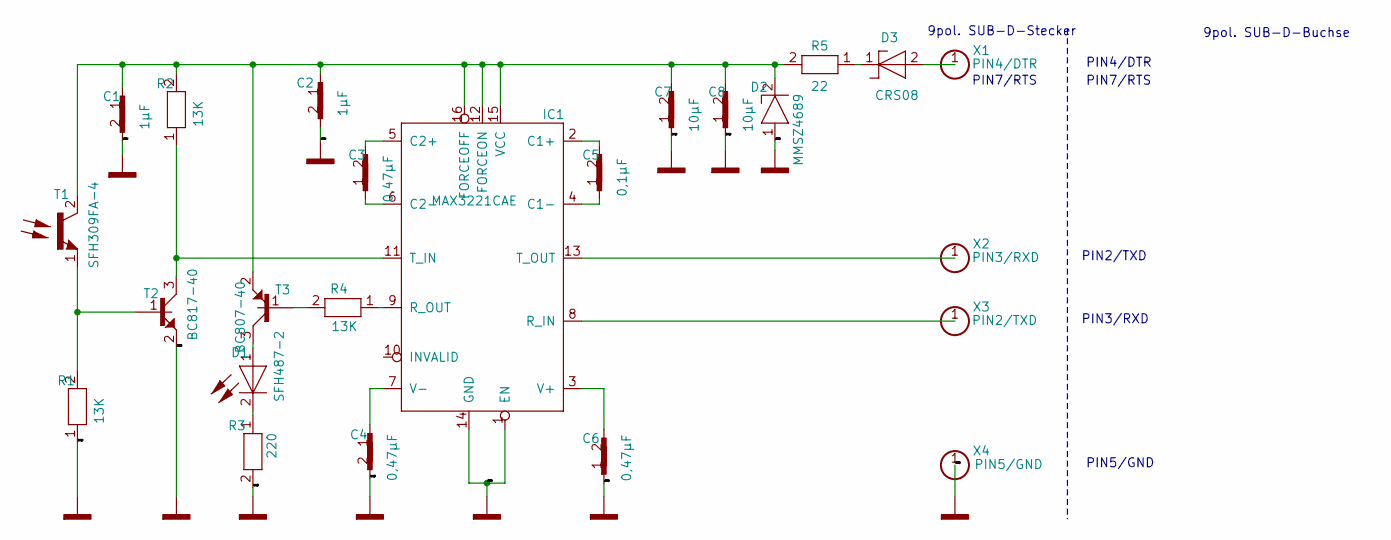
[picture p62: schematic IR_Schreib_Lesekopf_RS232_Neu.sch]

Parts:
C1: 1µF; 0603_KLEIN_25
C2: 1µF; 1206_29
C3: 0,47µF; 0603_13
C4: 0,47µF; 0603_0
C5: 0,1µF; 0603_12
C6: 0,47µF; 0603_1
C7: 10µF; 0805_KLEIN_34
C8: 10µF; 0805_KLEIN_2
D1: SFH487-2; LED_3MM_26
D2: MMSZ4689; DO214AA_15
D3: CRS08; SOD123_17
IC1: MAX3221CAE; SSOP16_11
R1: 13K; 0603_KLEIN_20
R2: 13K; 0603_KLEIN_21
R3: 220; 0603_KLEIN_31
R4: 13K; 0603_KLEIN_27
R5: 22; 1206_18
T1: SFH309FA-4; FOTO_4MM_19
T2: BC817-40; SOT23_3_33
T3: BC807-40; SOT23_3_32
X1: PIN4/DTR; LOETPUNKT_7
X2: PIN3/RXD; LOETPUNKT_9
X3: PIN2/TXD; LOETPUNKT_8
X4: PIN5/GND; LOETPUNKT_10

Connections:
1: C1.2, C2.2, C4.2, C6.1, C7.1, C8.1, D2.1, IC1.1 (EN), IC1.14 (GND), R1.1, R3.2, T2.2, X4.1
unnamed: C1.1, C2.1, C7.2, C8.2, D2.2, IC1.12 (FORCEON), IC1.15 (VCC), IC1.16 (FORCEOFF), R2.2, R5.2, T1.2, T3.2
unnamed: C3.1, IC1.6 (C2-)
unnamed: C3.2, IC1.5 (C2+)
unnamed: C4.1, IC1.7 (V-)
unnamed: C5.1, IC1.4 (C1-)
unnamed: C5.2, IC1.2 (C1+)
unnamed: C6.2, IC1.3 (V+)
unnamed: D1.2, R3.1
unnamed: D3.1, R5.1
unnamed: D3.2, X1.1
unnamed: IC1.8 (R_IN), X3.1
unnamed: IC1.9 (R_OUT), R4.1
unnamed: IC1.11 (T_IN), R2.1
unnamed: IC1.13 (T_OUT), X2.1
unnamed: R1.2, T1.1

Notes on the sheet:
9pol. SUB-D-Stecker
PIN7/RTS
PIN4/DTR
PIN2/TXD
PIN3/RXD
PIN5/GND
9pol. SUB-D-Buchse

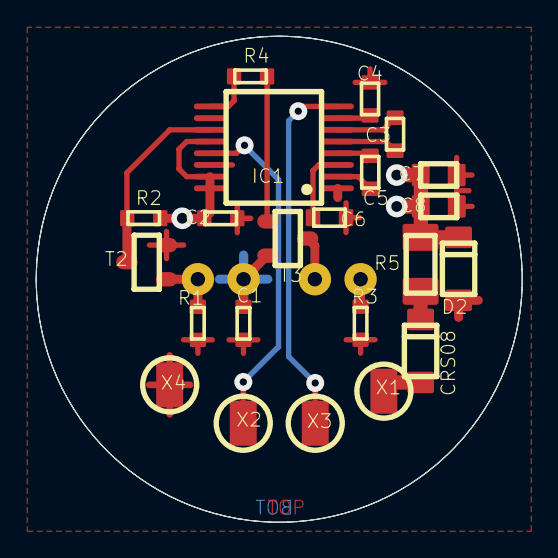
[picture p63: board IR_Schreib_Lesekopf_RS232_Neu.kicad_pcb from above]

Board: 2 copper layers, 27.0 x 27.0 mm, 24 parts (0 on the bottom side), 16 nets.

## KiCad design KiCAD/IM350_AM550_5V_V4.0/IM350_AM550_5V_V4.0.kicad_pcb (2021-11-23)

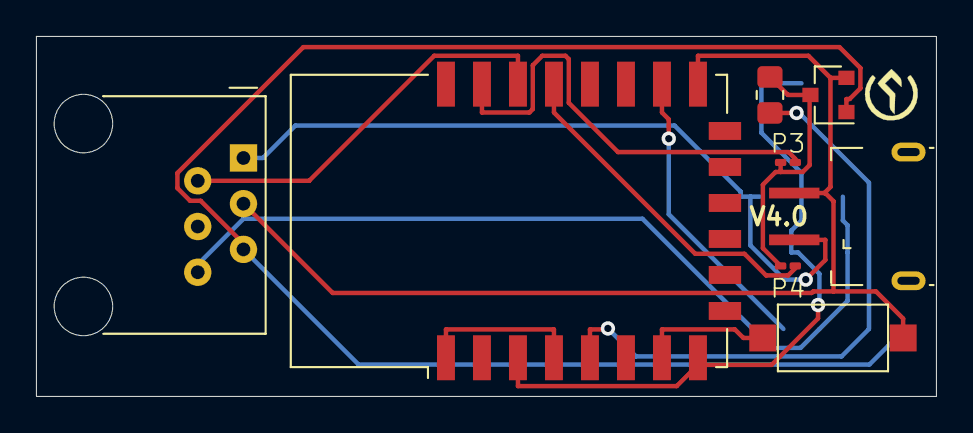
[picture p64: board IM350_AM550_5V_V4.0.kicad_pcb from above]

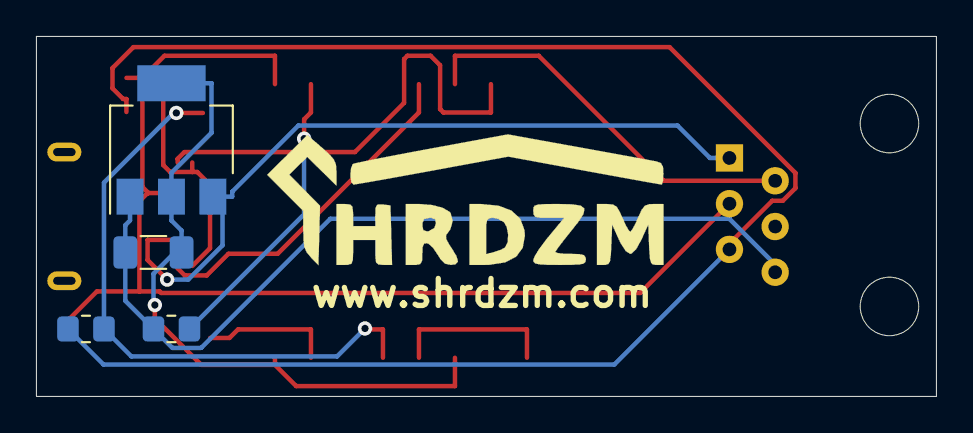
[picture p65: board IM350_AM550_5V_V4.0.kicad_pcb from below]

Board: 2 copper layers, 50.0 x 20.0 mm, 14 parts (5 on the bottom side), 12 nets.

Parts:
C1: 22uF; C_1206_3216Metric_Pad1.33x1.80mm_HandSolder
G1: LOGO; SHRDZM 22x7
G2: LOGO; SHRDZM Symbol 3x3
J1: USB_B_Micro_Power; USB_Micro-B_Power
J2: RJ12; RJ12_Amphenol_54601
P3, P4: 0; R_0201_0603Metric_Pad0.64x0.40mm_HandSolder
Q1: BC847; SOT-23
R3: 2.2k; R_0805_2012Metric_Pad1.20x1.40mm_HandSolder
R4, R5: 10k; R_0805_2012Metric_Pad1.20x1.40mm_HandSolder
SW1: SW_Push; SW_SPST_CK_RS282G05A3
U1: AMS1117-3.3; SOT-223-3_TabPin2
U2: ESP-12F; ESP-12E

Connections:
unnamed: C1.1, U1.2, U2.3, U2.8
unnamed: C1.2, J1.5, J2.3, J2.6, Q1.2, R3.2, SW1.2, U1.1, U2.15
unnamed: J1.1, J2.1, U1.3
unnamed: J2.2, U2.20
unnamed: J2.5, Q1.1, R5.2
unnamed: P3.1, P4.1, Q1.3, R4.2
unnamed: P3.2, U2.21
unnamed: P4.2, U2.19
unnamed: R3.1, U2.16
unnamed: R4.1, R5.1, U2.5
unnamed: SW1.1, U2.7
unnamed: U2.1, U2.4

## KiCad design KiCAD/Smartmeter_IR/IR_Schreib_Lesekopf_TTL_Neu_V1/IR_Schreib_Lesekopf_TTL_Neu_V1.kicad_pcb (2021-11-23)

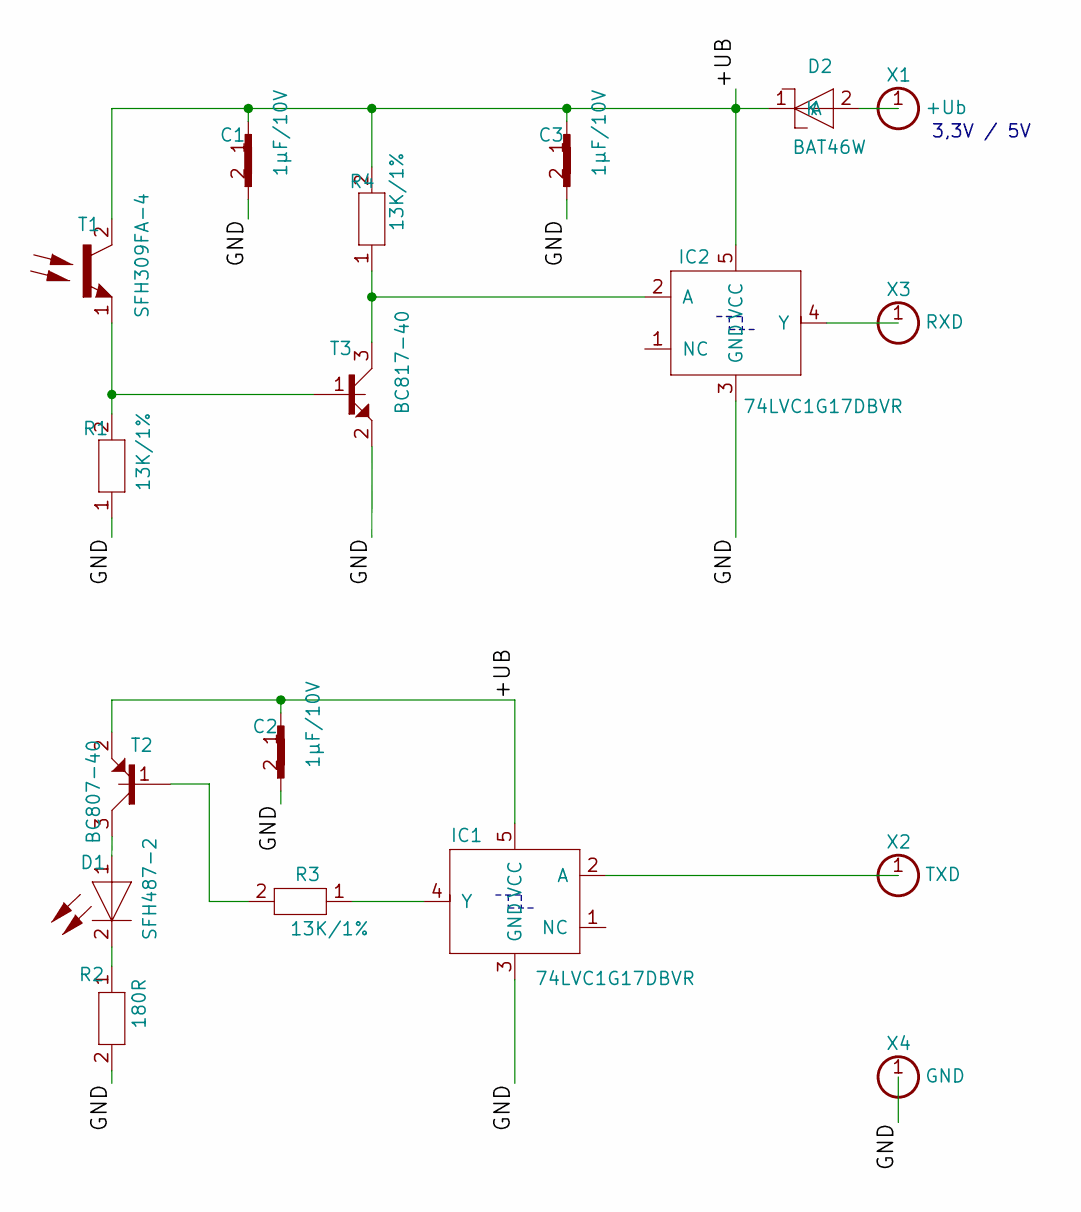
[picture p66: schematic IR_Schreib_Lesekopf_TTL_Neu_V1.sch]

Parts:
C1: 1µF/10V; 0805_11
C2: 1µF/10V; 0805_21
C3: 1µF/10V; 0805_10
D1: SFH487-2; LED_3MM_13
D2: BAT46W; SOD123_25
IC1: 74LVC1G17DBVR; SOT23_5_20
IC2: 74LVC1G17DBVR; SOT23_5_23
R1: 13K/1%; 0805_5
R2: 180R; 0805_27
R3: 13K/1%; 0805_14
R4: 13K/1%; 0805_6
T1: SFH309FA-4; FOTO_4MM_4
T2: BC807-40; SOT23_3_28
T3: BC817-40; SOT23_3_26
X1: +Ub; LOETPUNKT_3
X2: TXD; LOETPUNKT_19
X3: RXD; LOETPUNKT_2
X4: GND; LOETPUNKT_1

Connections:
/+UB: C1.1, C2.1, C3.1, D2.1 (K), IC1.5 (VCC), IC2.5 (VCC), R4.2, T1.2
/GND: C1.2, C2.2, C3.2, IC1.3 (GND), IC2.3 (GND), R1.1, R2.2, X4.1
unnamed: D1.1, T2.3
unnamed: D1.2, R2.1
unnamed: D2.2 (A), X1.1
unnamed: IC1.2 (A), X2.1
unnamed: IC1.4 (Y), R3.1
unnamed: IC2.2 (A), R4.1, T3.3
unnamed: IC2.4 (Y), X3.1
unnamed: R1.2, T1.1, T3.1

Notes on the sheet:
3,3V / 5V

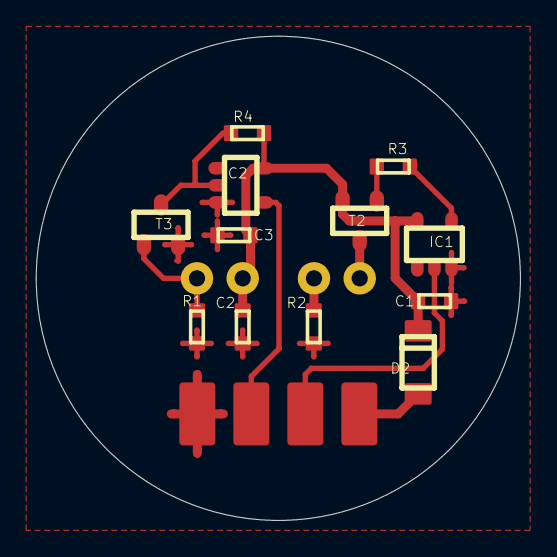
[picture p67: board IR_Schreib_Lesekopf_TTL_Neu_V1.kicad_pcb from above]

Board: 2 copper layers, 26.9 x 26.9 mm, 18 parts (0 on the bottom side), 10 nets.

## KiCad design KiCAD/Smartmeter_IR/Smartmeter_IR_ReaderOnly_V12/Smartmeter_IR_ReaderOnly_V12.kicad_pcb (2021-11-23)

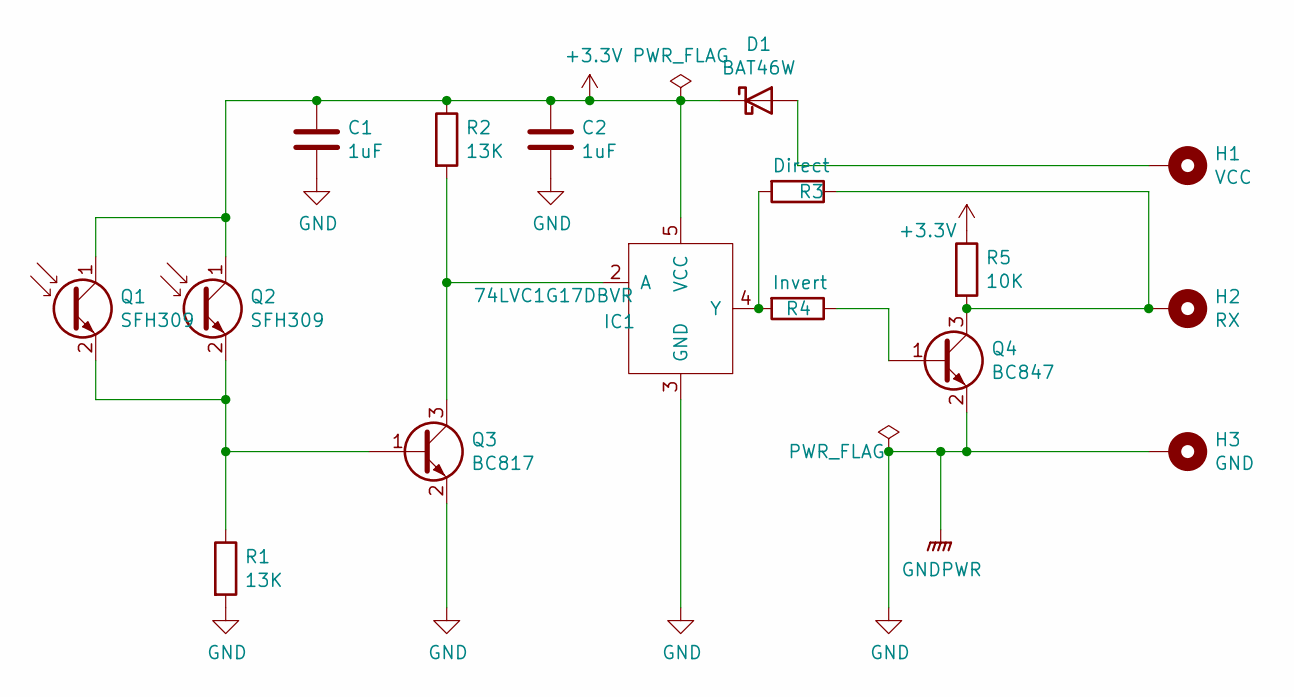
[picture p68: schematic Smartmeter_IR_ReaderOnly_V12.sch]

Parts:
C1, C2: 1uF; C_0603_1608Metric_Pad1.08x0.95mm_HandSolder
D1: BAT46W; D_SOD-123
H1: VCC; SolderWirePad_1x01_SMD_1x2mm
H2: RX; SolderWirePad_1x01_SMD_1x2mm
H3: GND; SolderWirePad_1x01_SMD_1x2mm
IC1: 74LVC1G17DBVR; SOT-23-5
Q1, Q2: SFH309; LED_D3.0mm
Q3: BC817; SOT-23
Q4: BC847; SOT-23
R1, R2: 13K; R_0603_1608Metric_Pad0.98x0.95mm_HandSolder
R3: Direct; R_0402_1005Metric_Pad0.72x0.64mm_HandSolder
R4: Invert; R_0402_1005Metric_Pad0.72x0.64mm_HandSolder
R5: 10K; R_0603_1608Metric_Pad0.98x0.95mm_HandSolder

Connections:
+3V3: C1.1, C2.1, D1.1 (K), IC1.5 (VCC), Q1.1 (C), Q2.1 (C), R2.1, R5.1
GND: C1.2, C2.2, H3.1, IC1.3 (GND), Q3.2 (E), Q4.2 (E), R1.2
unnamed: D1.2 (A), H1.1
unnamed: H2.1, Q4.3 (C), R3.1, R5.2
unnamed: IC1.2 (A), Q3.3 (C), R2.2
unnamed: IC1.4 (Y), R3.2, R4.2
unnamed: Q1.2 (E), Q2.2 (E), Q3.1 (B), R1.1
unnamed: Q4.1 (B), R4.1

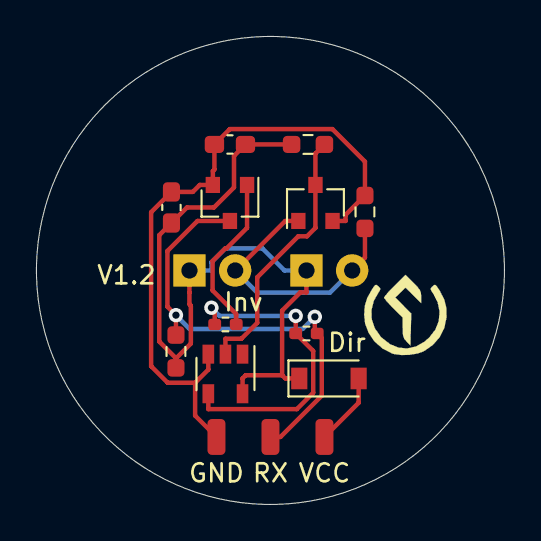
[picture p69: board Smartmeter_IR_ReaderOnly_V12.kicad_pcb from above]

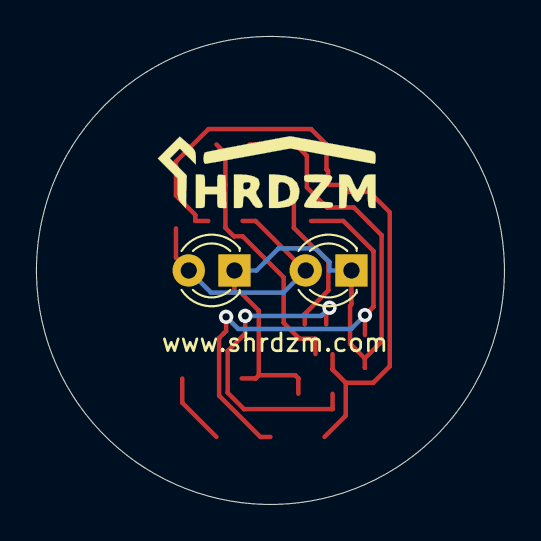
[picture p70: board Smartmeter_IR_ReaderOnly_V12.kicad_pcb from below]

Board: 2 copper layers, 26.0 x 26.0 mm, 18 parts (3 on the bottom side), 8 nets.

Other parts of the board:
G1: LOGO; SHRDZM 12x4
G2: LOGO; SHRDZM Symbol 5x5

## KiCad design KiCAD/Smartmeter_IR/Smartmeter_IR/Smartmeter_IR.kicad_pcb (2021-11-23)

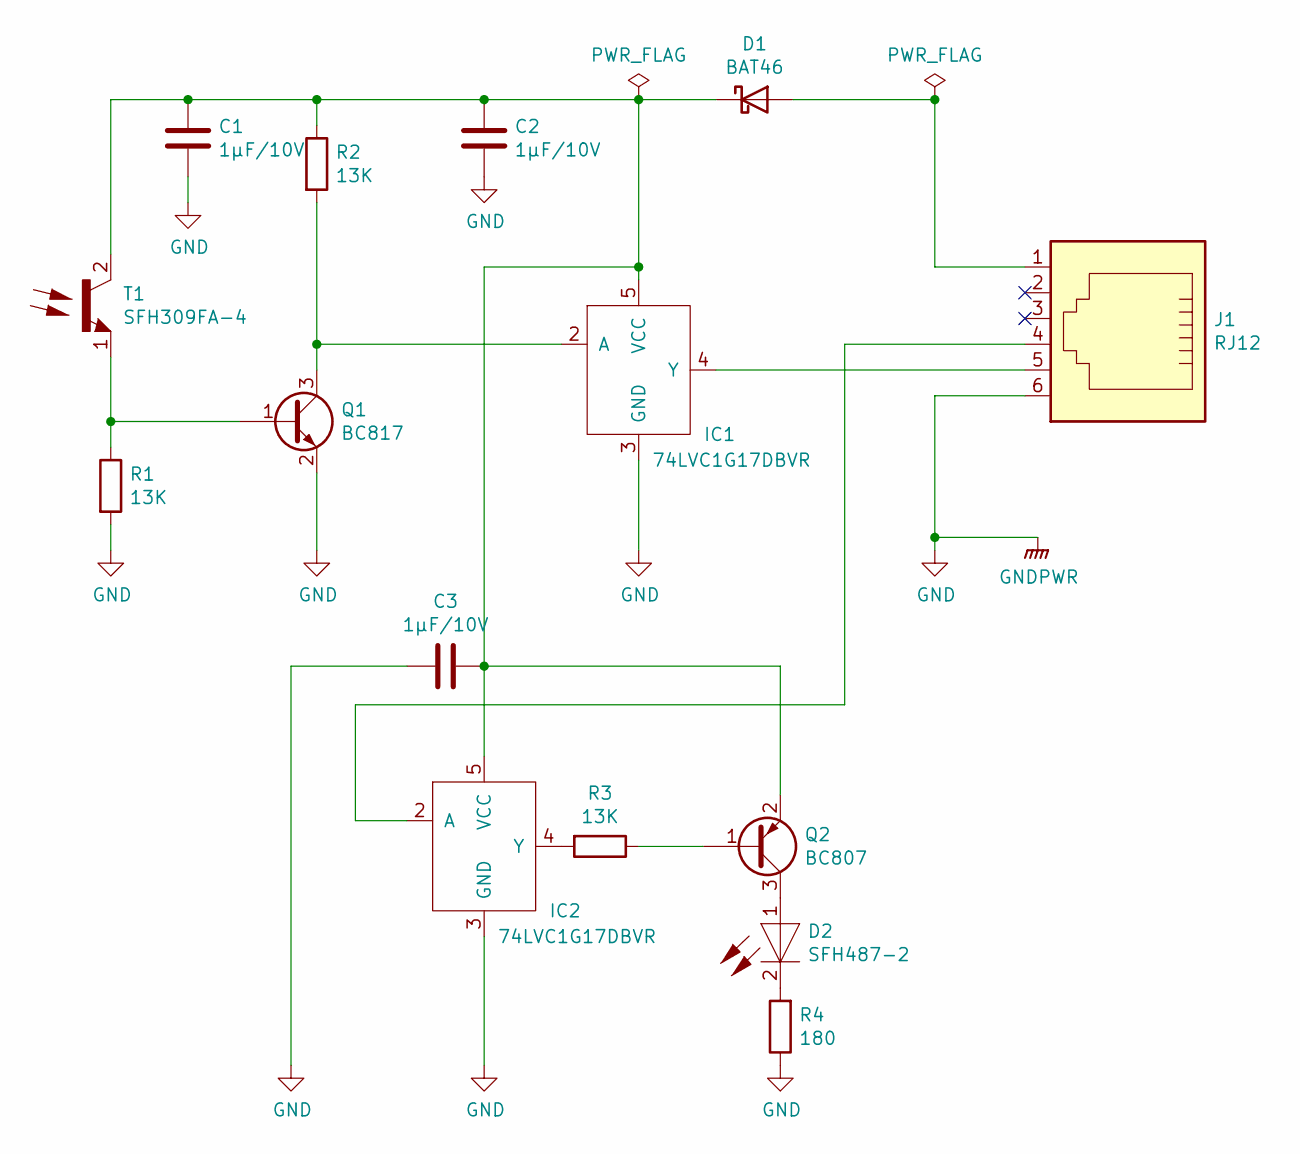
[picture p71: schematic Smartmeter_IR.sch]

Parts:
C1, C2, C3: 1µF/10V; C_0805_2012Metric_Pad1.18x1.45mm_HandSolder
D1: BAT46; D_SOD-123
D2: SFH487-2; LED_3MM_26
IC1, IC2: 74LVC1G17DBVR; SOT-23-5
J1: RJ12; RJ12_Amphenol_54601
Q1: BC817; SOT-23
Q2: BC807; SOT-23
R1, R2, R3: 13K; R_0805_2012Metric_Pad1.20x1.40mm_HandSolder
R4: 180; R_0805_2012Metric_Pad1.20x1.40mm_HandSolder
T1: SFH309FA-4; FOTO_4MM_19

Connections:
GND: C1.2, C2.2, C3.2, IC1.3 (GND), IC2.3 (GND), J1.6, Q1.2 (E), R1.2, R4.1
unnamed: C1.1, C2.1, C3.1, D1.1 (K), IC1.5 (VCC), IC2.5 (VCC), Q2.2 (E), R2.1, T1.2
unnamed: D1.2 (A), J1.1
unnamed: D2.1, Q2.3 (C)
unnamed: D2.2, R4.2
unnamed: IC1.2 (A), Q1.3 (C), R2.2
unnamed: IC1.4 (Y), J1.5
unnamed: IC2.2 (A), J1.4
unnamed: IC2.4 (Y), R3.2
unnamed: Q1.1 (B), R1.1, T1.1
unnamed: Q2.1 (B), R3.1

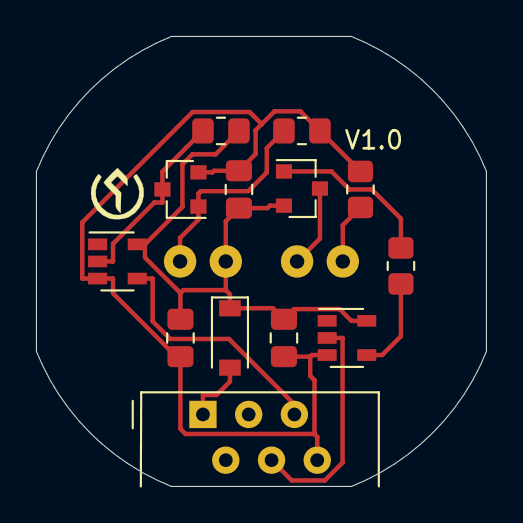
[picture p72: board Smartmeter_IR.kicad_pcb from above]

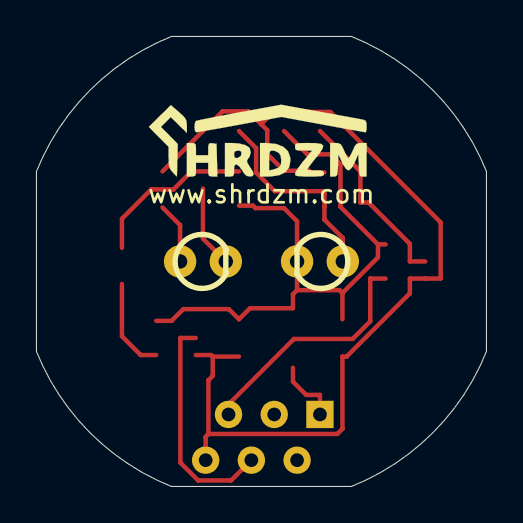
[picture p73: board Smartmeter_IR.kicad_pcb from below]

Board: 2 copper layers, 25.0 x 25.0 mm, 17 parts (2 on the bottom side), 11 nets.

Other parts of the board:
G1: LOGO; SHRDZM 12x4
G2: LOGO; SHRDZM Symbol 3x3

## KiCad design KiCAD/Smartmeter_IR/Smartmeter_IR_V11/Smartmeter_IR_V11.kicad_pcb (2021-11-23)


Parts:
C1, C2, C3: 1uF; C_0603_1608Metric_Pad1.08x0.95mm_HandSolder
D1: SFH487-2; LED_D3.0mm
D2: BAT46W; D_SOD-123
IC1, IC2: 74LVC1G17DBVR; SOT-23-5
J1: RJ12; RJ12_Amphenol_54601_Reduced
R1, R2, R3, R4: 13K; R_0603_1608Metric_Pad0.98x0.95mm_HandSolder
T1: SFH309FA-4; LED_D3.0mm
T2: BC807-40; SOT-23
T3: BC817; SOT-23

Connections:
GND: C1.2, C2.2, C3.2, IC1.3 (GND), IC2.3 (GND), J1.6, R1.2, R2.1, T3.2 (E)
unnamed: D1.1, T2.3 (C)
unnamed: D1.2, R2.2
unnamed: D2.2 (A), J1.1
unnamed: IC1.2 (A), J1.4
unnamed: IC1.4 (Y), R3.1
unnamed: IC2.2 (A), R4.2, T3.3 (C)
unnamed: IC2.4 (Y), J1.5
unnamed: R1.1, T1.1, T3.1 (B)
unnamed: R3.2, T2.1 (B)
PWR: C1.1, C2.1, C3.1, D2.1 (K), IC1.5 (VCC), IC2.5 (VCC), R4.1, T1.2, T2.2 (E)



Board: 2 copper layers, 25.0 x 25.0 mm, 15 parts (2 on the bottom side), 11 nets.

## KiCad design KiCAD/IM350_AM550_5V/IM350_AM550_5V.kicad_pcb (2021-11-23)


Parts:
C2: 100nF; C_Disc_D6.0mm_W2.5mm_P5.00mm
D1, D2: 1N4148; D_0805_2012Metric_Pad1.15x1.40mm_HandSolder
J5: USB_B_Micro_Power; USB_Micro-B_Power
J7: RJ12; RJ12_Amphenol_54601_Reduced
R1, R5: 10k; R_Axial_DIN0207_L6.3mm_D2.5mm_P2.54mm_Vertical
SW1: Pairing; SW_PUSH_6mm
U1: MCP1700-3302E_SOT23; SOT-23_Handsoldering
U2: ESP-12F; ESP-12E

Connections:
+3V3: C2.1, U1.2 (VO), U2.3 (EN), U2.8 (VCC)
/GPIO3: D1.1 (K), U2.21 (GPIO3/RXD)
/GPIO4: D2.1 (K), U2.19 (GPIO4)
unnamed: C2.2, J5.5 (GND), J7.3, J7.6, R1.2, SW1.2, U1.1 (GND), U2.15 (GND)
unnamed: D1.2 (A), D2.2 (A), J7.5, R5.2
unnamed: J5.1 (VBUS), U1.3 (VI)
unnamed: J7.1, R5.1, U2.5 (GPIO14)
unnamed: J7.2, U2.20 (GPIO5)
unnamed: R1.1, U2.16 (GPIO15)
unnamed: SW1.1, U2.7 (GPIO13)
unnamed: U2.1 (~RST), U2.4 (GPIO16)


Board: 2 copper layers, 59.0 x 20.0 mm, 12 parts (1 on the bottom side), 11 nets.

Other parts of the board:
G1: LOGO; SHRDZM 22x7
G2: LOGO; SHRDZM Symbol 3x3

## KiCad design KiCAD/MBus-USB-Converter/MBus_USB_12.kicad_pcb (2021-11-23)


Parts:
C1, C2, C3, C4: CP; CP_Radial_D5.0mm_P2.50mm
D1: LED; LED_D3.0mm
J1, J2: TerminalBlock_bornier-2_P5.08mm
J3: Conn_01x04_Female; TerminalBlock_bornier-4_P5.08mm
J4: Conn_01x03_Female; TerminalBlock_bornier-3_P5.08mm
Q1: BC337; TO-92_Molded_Wide_Oval
Q2: BD136; TO-126_Vertical
R1: 270; R_Axial_DIN0207_L6.3mm_D2.5mm_P10.16mm_Horizontal
R2: 1k; R_Axial_DIN0207_L6.3mm_D2.5mm_P10.16mm_Horizontal
R3: 33k; R_Axial_DIN0207_L6.3mm_D2.5mm_P10.16mm_Horizontal
R4: 18k; R_Axial_DIN0207_L6.3mm_D2.5mm_P10.16mm_Horizontal
R5: 2k7; R_Axial_DIN0207_L6.3mm_D2.5mm_P10.16mm_Horizontal
R6: 220k; R_Axial_DIN0207_L6.3mm_D2.5mm_P10.16mm_Horizontal
R7: 39; R_Axial_DIN0207_L6.3mm_D2.5mm_P10.16mm_Horizontal
U1, U2: LTV-817; DIP-4_W7.62mm_LongPads
U3: MAX232; DIP-16_W7.62mm_LongPads
U4: NMA0515DC; DCDC-Conv_muRata_NMAxxxxDC
U5: NMA0512SC; DCDC-Conv_muRata_NMAxxxxSC

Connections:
34V: D1.2 (A), J1.2, J2.1, R3.1, R6.1, U4.9 (VOUT+), U5.6 (VOUT+)
+5V: C2.2, J3.4, R2.1, U3.16 (VCC), U4.14 (VIN+), U5.1 (VIN+)
GND: J1.1, Q1.3 (E), R4.2, R7.2, U2.3, U4.11 (VOUT-), U5.4 (VOUT-)
GNDA: C1.1, J3.1, J4.1, U1.3, U2.2, U3.15 (GND), U4.1 (VIN-), U5.2 (VIN-)
unnamed: C1.2, U3.6 (VS-)
unnamed: C2.1, U3.2 (VS+)
unnamed: C3.1, U3.4 (C2+)
unnamed: C3.2, U3.5 (C2-)
unnamed: C4.1, U3.1 (C1+)
unnamed: C4.2, U3.3 (C1-)
unnamed: D1.1 (K), R5.1
unnamed: J2.2, Q2.1 (E), R6.2
unnamed: J3.2, R1.2, U3.9 (R2OUT)
unnamed: J3.3, R2.2, U1.4, U3.10 (T2IN)
unnamed: J4.2, U3.7 (T2OUT)
unnamed: J4.3, U3.8 (R2IN)
unnamed: Q1.1 (C), U1.2
unnamed: Q1.2 (B), Q2.2 (C), R7.1
unnamed: Q2.3 (B), R3.2, R4.1, U2.4
unnamed: R1.1, U2.1
unnamed: R5.2, U1.1

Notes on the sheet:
3,3V or 5V
RxD
TxD
USB µController ATMega Arduino RaspberryPi ...
MBus Master
+34V
GND
GND (A)
5V (3,3V)
DC/DC Konverter (universal)
RECOM RGZ515D RECOM RGZ3.315D (3,3V) TRACO Power TMH0515D aimtec AM2D-0515SDZ
RS232
M-Bus


Board: 2 copper layers, 74.0 x 41.0 mm, 23 parts (0 on the bottom side), 21 nets.

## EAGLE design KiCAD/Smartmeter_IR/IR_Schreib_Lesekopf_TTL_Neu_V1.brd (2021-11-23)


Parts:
C1: 1µF/10V; 0805_11
C2: 1µF/10V; 0805_21
C3: 1µF/10V; 0805_10
D1: SFH487-2; LED_3MM_13
D2: BAT46W; SOD123_25
IC1: 74LVC1G17DBVR; SOT23/5_20
IC2: 74LVC1G17DBVR; SOT23/5_23
R1: 13K/1%; 0805_5
R2: 180R; 0805_27
R3: 13K/1%; 0805_14
R4: 13K/1%; 0805_6
T1: SFH309FA-4; FOTO_4MM_4
T2: BC807-40; SOT23/3_28
T3: BC817-40; SOT23/3_26
X1: +Ub; LOETPUNKT_3
X2: TXD; LOETPUNKT_19
X3: RXD; LOETPUNKT_2
X4: GND; LOETPUNKT_1

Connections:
1: IC1.4 (Y), R3.1
+: R1.2, T1.1, T3.1
+UB: C1.1, C2.1, C3.1, D2.1 (K), IC1.5 (VCC), IC2.5 (VCC), R4.2, T1.2, T2.2
A: D2.2 (A), X1.1
B: R3.2, T2.1
C: D1.1, T2.3
GND: C1.2, C2.2, C3.2, IC1.3 (GND), IC2.3 (GND), R1.1, R2.2, T3.2, X4.1
K: D1.2, R2.1
OUT: IC2.2 (A), R4.1, T3.3
SIG$4: IC1.2 (A), X2.1
SIG$5: IC2.4 (Y), X3.1

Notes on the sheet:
3,3V / 5V


Board: 2 copper layers, 26.9 x 26.9 mm, 18 parts (1 on the bottom side), 11 nets.

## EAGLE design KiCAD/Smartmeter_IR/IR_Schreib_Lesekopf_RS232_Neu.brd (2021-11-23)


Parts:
C1: 1µF; 0603_KLEIN_25
C2: 1µF; 1206_29
C3: 0,47µF; 0603_13
C4: 0,47µF; 0603_0
C5: 0,1µF; 0603_12
C6: 0,47µF; 0603_1
C7: 10µF; 0805_KLEIN_34
C8: 10µF; 0805_KLEIN_2
D1: SFH487-2; LED_3MM_26
D2: MMSZ4689; DO214AA_15
D3: CRS08; SOD123_17
IC1: MAX3221CAE; SSOP16_11
R1: 13K; 0603_KLEIN_20
R2: 13K; 0603_KLEIN_21
R3: 220; 0603_KLEIN_31
R4: 13K; 0603_KLEIN_27
R5: 22; 1206_18
T1: SFH309FA-4; FOTO_4MM_19
T2: BC817-40; SOT23/3_33
T3: BC807-40; SOT23/3_32
X1: PIN4/DTR; LOETPUNKT_7
X2: PIN3/RXD; LOETPUNKT_9
X3: PIN2/TXD; LOETPUNKT_8
X4: PIN5/GND; LOETPUNKT_10

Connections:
2: D3.1, R5.1
+: R1.2, T1.1, T2.1
B: R4.2, T3.1
C: D1.1, T3.3
C1+: C5.2, IC1.2 (C1+)
C1-: C5.1, IC1.4 (C1-)
C2+: C3.2, IC1.5 (C2+)
C2-: C3.1, IC1.6 (C2-)
GND: C1.2, C2.2, C4.2, C6.1, C7.1, C8.1, D2.1, IC1.1 (EN), IC1.14 (GND), R1.1, R3.2, T2.2, X4.1
K: D1.2, R3.1
PIN1: D3.2, X1.1
RXD: IC1.11 (T_IN), R2.1, T2.3
R_OUT: IC1.9 (R_OUT), R4.1
SIG$10: IC1.13 (T_OUT), X2.1
SIG$11: IC1.8 (R_IN), X3.1
V+: C6.2, IC1.3 (V+)
V-: C4.1, IC1.7 (V-)
VCC: C1.1, C2.1, C7.2, C8.2, D2.2, IC1.12 (FORCEON), IC1.15 (VCC), IC1.16 (FORCEOFF), R2.2, R5.2, T1.2, T3.2

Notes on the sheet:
9pol. SUB-D-Stecker
PIN7/RTS
PIN4/DTR
PIN2/TXD
PIN3/RXD
PIN5/GND
9pol. SUB-D-Buchse


Board: 2 copper layers, 27.0 x 27.0 mm, 24 parts (1 on the bottom side), 18 nets.

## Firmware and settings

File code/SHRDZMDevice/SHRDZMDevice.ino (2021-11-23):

/*
  SHRDZMDevice

  Created 20 Jul 2020
  By Erich O. Pintar
  Modified 26 December 2020
  By Erich O. Pintar

  https://github.com/saghonfly

*/

#define DEBUG_SHRDZM

#include "config/config.h"

Configuration configuration;
SimpleEspNowConnection simpleEspConnection(SimpleEspNowRole::CLIENT);
DeviceBase* dev;
DeviceBase* settingDev = NULL;
String ver, nam;
bool firmwareUpdate = false;
bool avoidSleeping = false;
bool batterycheckDone = false;
bool canGoDown = false;
bool forceSleep = false;
bool loopDone = false;
bool initReboot = false;
bool sendBufferFilled = false;
bool isDeviceInitialized = false;
bool pairingOngoing = false;
bool finishSent = false;
bool processendSet = false;
bool processendReached = false;
bool configurationMode = false;
bool gatewayMode = false;
bool firstMeasurement = true;
String SSID;
String password;
String host;
String url;
unsigned long clockmillis = 0;
unsigned long prepareend = 0;
unsigned long processend = 0;
unsigned long lastIntervalTime = 0;
unsigned long preparestart = 0;
unsigned long currentUptime = 0;
unsigned long configurationAPWaitStartTime = 0;
unsigned long configurationAPWaitOngoingStartTime = 0;
bool finalMeasurementDone = false;
bool setNewDeviceType = false;
bool preparing = false;
bool configurationAPWaiting = false;
bool configurationAPWaitOngoing = false;
String newDeviceType = "";
String deviceName;
bool sleepEnabled = true;
String lastRebootInfo = "";
bool apConnectingOngoing = false;
unsigned long apConnectionStartTime = 0;
unsigned long mqttNextTry = 0;
bool writeConfiguration = false;
Ticker configurationBlinker;
ESP8266WebServer server;
WiFiClient espClient;
PubSubClient mqttclient(espClient);
String MQTT_TOPIC = "SHRDZM/";
String subcribeTopicSet;
String subscribeTopicConfig;
char websideBuffer[6500];
char menuContextBuffer[4300];
char contentBuffer[750];
const uint16_t ajaxIntervall = 2;
String lastMessage = "";
bool cloudConnected = false;
String cloudToken = "";
String cloudID = "";
bool cloudIsDeviceRegistered = false;
time_t now;                         
tm tm; 
asyncHTTPrequest request;

typedef struct struct_esp_message {
  char prefix = '.';
  char type;
  long sendTime;
  uint8_t pc; // package count
  uint8_t p;  // package
  uint8_t len;
  char message[200];
  uint16_t checksum;
} esp_message;

/// Send ESP Message with checksum
void sendMessageWithChecksum(const char *message)
{
  uint8_t packages = strlen(message) / 200 + 1;
  long sendtime = millis();

  for(int i = 0; i<packages; i++)
  {
    esp_message em;
    
    em.type = 'F';
    em.sendTime = sendtime;
    em.pc = packages;
    em.p = i+1;
    em.len = strlen(message);    

    sprintf(em.message, message, strlen(message));
    em.checksum = simpleEspConnection.calculateChecksum(message);
  
    simpleEspConnection.sendMessage((uint8_t*)&em, sizeof(em));  
  }  
}

void controlConnectionBlinker(bool enabled)
{
#ifdef LEDPIN
    pinMode(LEDPIN, OUTPUT);  
    if(enabled)
    {
      configurationBlinker.attach(2.0, changeConfigurationBlinker);
    }
    else
    {
      configurationBlinker.detach(); 
      digitalWrite(LEDPIN, HIGH);
    }
#endif    
}

/// Configuration Webserver
void startConfigurationAP()
{
  configurationMode = true;
    
  String APName = "SHRDZMDevice-"+deviceName;
  WiFi.hostname(APName.c_str());        
  WiFi.softAP(APName);     

  DLN(F("Start configuration AP..."));
  
  server.on(F("/"), handleRoot);
  server.on(F("/reboot"), handleReboot);
  server.on(F("/general"), handleRoot);
  server.on(F("/settings"), handleSettings);
  server.on(F("/gateway"), handleGateway);
  server.on(F("/NTP"), handleNTP);
  server.on(F("/cloud"), handleCloud);
  server.onNotFound(handleNotFound);
  server.begin();


#ifdef LEDPIN
    pinMode(LEDPIN, OUTPUT);
#endif
  
  configurationBlinker.attach(0.2, changeConfigurationBlinker);
}

char* getWebsite(char* content, bool update = false)
{  
  int len = strlen(content);

  DLN("Content len = "+String(len));

  sprintf(websideBuffer,  
    website_template,
    update ? F("<script src=\"j.js\"></script>") : F(""), 
    deviceName.c_str(), deviceName.c_str(), content);

  return websideBuffer;
}

void handleJson() {
  // Output: send data to browser as JSON
  String message = "";

  time(&now);
  localtime_r(&now, &tm);

  char t[22];
  sprintf(t, "%4d-%02d-%02d %02d:%02d:%02d", tm.tm_year + 1900, tm.tm_mon + 1, tm.tm_mday, tm.tm_hour, tm.tm_min, tm.tm_sec );

  message += (F("{\"mqttconnectionstate\":"));
  if(strcmp(configuration.getWlanParameter("MQTTenabled"), "true") == 0)
    message += (mqttclient.connected() ? F("\"Connected\"") : F("\"Not Connected\""));  
  else
    message += F("\"Disabled\"");    
  message += (F(",\"lastmessage\":"));
  message += lastMessage;  
  message += (F(",\"timestamp\":\""));
  message += String(t);  
  message += (F("\"}")); // End of JSON
  server.send(200, F("application/json"), message);
}

void handleJs()
{
  String message;
  message += F("const url ='json';\n"
               "function renew(){\n"
               " fetch(url)\n" // Call the fetch function passing the url of the API as a parameter
               " .then(response => {return response.json();})\n"
               " .then(jo => {\n"
               "   for (var i in jo)\n"
               "    {if (document.getElementById(i))\n"
               "      {\n"
               "          document.getElementById(i).innerHTML = jo[i];}\n"              
               "      }\n"
               " })\n"
               " .catch(function() {\n"                                        // this is where you run code if the server returns any errors
               " });\n"
               "}\n"
               "document.addEventListener('DOMContentLoaded', renew, setInterval(renew, ");
  message += ajaxIntervall * 1000;
  message += F("));");

  server.send(200, F("text/javascript"), message);
}

void handleRoot() 
{
  memset(contentBuffer, 0, sizeof(contentBuffer));

  if(server.hasArg(F("factoryreset")))
  {
    if(String(server.arg(F("factoryreset"))) == F("true")) // factory reset was pressed
    {
      snprintf(contentBuffer, 300,
       factoryreset_template      
      );
        
      server.send(200, F("text/html"), contentBuffer);

      configuration.resetConfiguration();

      delay(2000);
      
      ESP.restart();        
    }
  }

  if(server.hasArg(F("upgrade")) && server.hasArg(F("upgradepath")))
  {
    if(String(server.arg(F("upgrade"))) == F("true")) // Upgrade was pressed
    {
      DLN("Upgrade from "+String(server.arg(F("upgradepath")))+" will be started...");
      if(updateFirmwareByMQTT(server.arg(F("upgradepath"))))
      {        
        firmwareUpdate = true;

        snprintf(contentBuffer, 300, upgrade_template);
          
        server.send(200, F("text/html"), contentBuffer);  
        return;      
      }
    }    
  }
  
  sprintf(contentBuffer,  
      informationtable_template,
      ver.c_str(), ESP.getSketchMD5().c_str(),
      configuration.get("devicetype"),
      ESP.getChipId(),
      configuration.getWlanParameter("enabled"),
      configuration.get("gateway"),
      configuration.get("gateway"),deviceName.c_str(),
      configuration.get("gateway"),deviceName.c_str(),
      WiFi.localIP().toString().c_str(),
      WiFi.dnsIP().toString().c_str(),
      WiFi.gatewayIP().toString().c_str(),
      WiFi.subnetMask().toString().c_str()
  );  

  Serial.println(strlen(contentBuffer));
  
  sprintf(menuContextBuffer,  
      handleRoot_template,
      contentBuffer,
      gatewayMode ? upgradetext_template : ""
  );  

  char * temp = getWebsite(menuContextBuffer, true);
  server.send(200, F("text/html"), temp);
}

void handleNotFound() 
{
  String message = F("File Not Found\n\n");
  message += F("URI: ");
  message += server.uri();
  message += F("\nMethod: ");
  message += (server.method() == HTTP_GET) ? "GET" : "POST";
  message += F("\nArguments: ");
  message += server.args();
  message += F("\n");

  for (uint8_t i = 0; i < server.args(); i++) {
    message += " " + server.argName(i) + ": " + server.arg(i) + "\n";
  }

  server.send(404, F("text/plain"), message);
}

void handleReboot() 
{
  char temp[300];
  
  snprintf(temp, 300, handleReboot_template);

  server.send(200, F("text/html"), temp);

  delay(2000);
  
  ESP.restart();  
}

void handleSettings()
{
  String deviceType;
  int loop = 0;
  JsonObject deviceParameter;
  SensorData* initialSettings = NULL;
  char parameterBuffer[2024];
  
  DV(sizeof(parameterBuffer));

  memset(contentBuffer, 0, sizeof(contentBuffer));
  memset(parameterBuffer, 0, sizeof(parameterBuffer));

  if(settingDev != NULL)
  {
    free(settingDev);
    settingDev = NULL;
  }

  if(server.hasArg(F("devicechanged")))
  {
    if(String(server.arg(F("devicechanged"))) == F("true")) // now to save the parameter to the configuration
    {
      configuration.removeAllDeviceParameter();
    }
  }  
  
  // check selected device
  if(server.hasArg(F("devices")))
    deviceType = server.arg(F("devices"));
  else
    deviceType = configuration.get("devicetype");       

  if(deviceType != "" && deviceType != F("UNKNOWN") && settingDev == NULL)
  {
    settingDev = createDeviceObject(deviceType.c_str());  
    settingDev->setConfigurationObject(configuration.getConfigDocument());
    settingDev->initialize();
  }
  else
  {
    configuration.removeAllDeviceParameter();
    configuration.set("devicetype", (char *)deviceType.c_str()); 

    writeConfiguration = true;          
    
    //configuration.store();    
  }
    
  // check if save was pressed
  if(server.hasArg(F("save")))
  {
    if(String(server.arg(F("save"))) == F("true")) // now to save the parameter to the configuration
    {
      configuration.set("devicetype", (char *)deviceType.c_str()); 
      
      JsonObject documentRoot = configuration.getConfigDocument()->as<JsonObject>();   
      for (JsonPair kv : documentRoot) 
      {
        if(server.hasArg(kv.key().c_str()))
        {
          configuration.set((char *)kv.key().c_str(), (char *)server.arg(kv.key().c_str()).c_str());
        }
      }   

      // get names for device parameter
      deviceParameter = settingDev->getDeviceParameter(); 
      if(!deviceParameter.isNull())
      {        
        for (JsonPair kv : deviceParameter)
        {
          if(server.hasArg(kv.key().c_str()))
          {
            configuration.setDeviceParameter(kv.key().c_str(), server.arg(kv.key().c_str()).c_str());
          }
          else
          {
            configuration.setDeviceParameter(kv.key().c_str(), kv.value().as<char*>());
          }
        }    
      }  

      writeConfiguration = true;          
    }
  }
  
  if(settingDev != NULL)
  {
    if(strcmp(configuration.get("devicetype"), deviceType.c_str()) == 0)    
    {
      deviceParameter = configuration.getDeviceParameter();
    }
    else
    {
      deviceParameter = settingDev->getDeviceParameter();
      initialSettings = settingDev->readInitialSetupParameter();           
    }

    // Show general parameter
    JsonObject documentRoot = configuration.getConfigDocument()->as<JsonObject>();   
    for (JsonPair kv : documentRoot) 
    {
      if(String(kv.key().c_str()) != F("device") && String(kv.key().c_str()) != F("wlan") && String(kv.key().c_str()) != F("devicetype") && String(kv.key().c_str()) != F("cloud"))
      {
        strcat_P(parameterBuffer, PSTR("<br/><br/><div><label for='"));
        strcat(parameterBuffer, kv.key().c_str());
        strcat_P(parameterBuffer, PSTR("'>"));
        strcat(parameterBuffer, kv.key().c_str());
        strcat_P(parameterBuffer, PSTR("</label>"));
        strcat_P(parameterBuffer, PSTR("<input type='text' id='"));
        strcat(parameterBuffer, kv.key().c_str());
        strcat_P(parameterBuffer, PSTR("' name='"));
        strcat(parameterBuffer, kv.key().c_str());
        strcat_P(parameterBuffer, PSTR("' size='10' value='"));
        
        if(initialSettings != NULL && initialSettings->getDataItem(kv.key().c_str()) != "")
        {
          strcat(parameterBuffer, initialSettings->getDataItemPtr(kv.key().c_str()));
        }
        else        
        {
          strcat(parameterBuffer, kv.value().as<char*>());
        }
                
        strcat_P(parameterBuffer, PSTR("'></div>"));        
      }
    }    

    // Show device parameter
    if(!deviceParameter.isNull())
    {
      strcat_P(parameterBuffer, PSTR("<br/>"));        
      
      for (JsonPair kv1 : deviceParameter)
      {
        strcat_P(parameterBuffer, PSTR("<br/><br/><div><label for='"));        
        strcat(parameterBuffer, kv1.key().c_str());
        strcat_P(parameterBuffer, PSTR("'>"));        
        strcat(parameterBuffer, kv1.key().c_str());
        strcat_P(parameterBuffer, PSTR("</label>"));        
        
        strcat_P(parameterBuffer, PSTR("<input type='text' id='"));        
        strcat(parameterBuffer, kv1.key().c_str());
        strcat_P(parameterBuffer, PSTR("' name='"));        
        strcat(parameterBuffer, kv1.key().c_str());
        strcat_P(parameterBuffer, PSTR("' size='10' value='"));        
        strcat(parameterBuffer, kv1.value().as<char*>());
        strcat_P(parameterBuffer, PSTR("'></div>"));        
      }    
    }    
  } 
    
  // Fill select box
  strcpy_P(contentBuffer, PSTR("<option></option>"));

  char rest[strlen(SUPPORTED_DEVICES+1)];
  strcpy(rest, SUPPORTED_DEVICES);

  char *ptr = strtok(rest, ",");  // takes a list of delimiters
  
  while(ptr != NULL)
  {
    if(strcmp(ptr, deviceType.c_str()) == 0)
    {
        strcat_P(contentBuffer, PSTR("<option selected>"));
        strcat(contentBuffer, ptr);
        strcat_P(contentBuffer, PSTR("</option>"));
    }
    else
    {
        strcat_P(contentBuffer, PSTR("<option>"));
        strcat(contentBuffer, ptr);
        strcat_P(contentBuffer, PSTR("</option>"));
    }

    ptr = strtok(NULL, ",");  // takes a list of delimiters
  }

  DV(strlen(parameterBuffer));


  sprintf(menuContextBuffer,  
      settings_template,
      contentBuffer,
      parameterBuffer
  );  

  char * temp = getWebsite(menuContextBuffer);
  DV(temp);
  DLN("after getWebsite size = "+String(strlen(temp)));

  server.send(200, F("text/html"), temp);  
}

void handleCloud()
{
  bool gatewayipset = WiFi.localIP().toString() != F("(IP unset)");
  
  if(server.args() != 0)
  {
    if( server.hasArg(F("cloudEnabledChanged")))
    {
      DV(String(server.arg(F("cloudEnabledChanged"))));
      if(String(server.arg(F("cloudEnabledChanged"))) == F("1")) 
      {
        if( server.hasArg(F("cloudenabled")))
        {
          if(String(server.arg(F("cloudenabled"))) == F("on"))
          {
            if(server.arg(F("user")) != "" && server.arg(F("password")) != "")
            {
              configuration.setCloudParameter("enabled", "true");

              if(gatewayipset)
              {
                if(cloudRegisterNewUser(server.arg("user").c_str(), "", server.arg("password").c_str()))
                {
                  cloudConnected = cloudLogin(server.arg("user").c_str(), server.arg("password").c_str());
                  if(cloudConnected)
                  {
                    configuration.setCloudParameter("userid", cloudID.c_str());
                    configuration.setCloudParameter("user", server.arg(F("user")).c_str());
                    configuration.setCloudParameter("password", server.arg(F("password")).c_str());
                    cloudRegisterDevice(deviceName.c_str(), configuration.get("devicetype"));
                  }
                }
              }
            }
            else
            {
              // show error
            }
          }
          else
          {
            if(gatewayipset)
            {
              cloudUnregisterDevice(deviceName.c_str());
              cloudUnregisterUser(configuration.getCloudParameter("user"), configuration.getCloudParameter("password"));
            }
            configuration.setCloudParameter("enabled", "false");
            configuration.setCloudParameter("userid", "");
          }
        }
        else
        {
          cloudUnregisterDevice(deviceName.c_str());
          cloudUnregisterUser(configuration.getCloudParameter("user"), configuration.getCloudParameter("password"));
          configuration.setCloudParameter("enabled", "false");
          configuration.setCloudParameter("userid", "");
        }
      }      
    }
    if( server.hasArg(F("resetCloudSettings")))
    {
      if(String(server.arg(F("resetCloudSettings"))) == F("true"))
      {
        if(gatewayipset)
        {
          cloudUnregisterDevice(deviceName.c_str());
          cloudUnregisterUser(configuration.getCloudParameter("userid"), configuration.getCloudParameter("password"));
        }        
        configuration.setCloudParameter("enabled", "false");
        configuration.setCloudParameter("user", deviceName.c_str());
        configuration.setCloudParameter("password", String(ESP.getChipId()).c_str());
      }
    }
    if(server.hasArg(F("privatecloudenabled")))
    {
      if( server.arg(F("privatecloudenabled")) == "1")
        configuration.setCloudParameter("privateenabled", "true");
      else
        configuration.setCloudParameter("privateenabled", "false");

      configuration.setCloudParameter("privateendpoint", server.arg(F("privateendpoint")).c_str());
      configuration.setCloudParameter("privateuser", server.arg(F("privateuser")).c_str());
      configuration.setCloudParameter("privatepassword", server.arg(F("privatepassword")).c_str());
      configuration.setCloudParameter("privateid", server.arg(F("privateid")).c_str());
    }
        
    writeConfiguration = true;          
  }  
  
  sprintf(menuContextBuffer, handleCloud_template,
      String(configuration.getCloudParameter("enabled")) == "true" ? "checked" : "",
      strcmp(configuration.getCloudParameter("user"), "") == 0 ? deviceName.c_str() :
        configuration.getCloudParameter("user"),
      strcmp(configuration.getCloudParameter("password"), "") == 0 ? String(ESP.getChipId()).c_str() :
        configuration.getCloudParameter("password"),
      (strlen(configuration.getCloudParameter("userid")) == 0) ? "<i><div style='color:#FF0000';>NOT REGISTERED</div></i>" : configuration.getCloudParameter("userid"),
      String(configuration.getCloudParameter("privateenabled")) == "true" ? "checked" : "",
      configuration.getCloudParameter("privateendpoint"),
      configuration.getCloudParameter("privateuser"),
      configuration.getCloudParameter("privatepassword"),
      strcmp(configuration.getCloudParameter("privateid"), "") == 0 ? deviceName.c_str() :
        configuration.getCloudParameter("privateid")
  );  

  char * temp = getWebsite(menuContextBuffer);

  server.send(200, F("text/html"), temp);    
}
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
void loop() 
{
  if(writeConfiguration)
  {
    writeConfiguration = false;
    configuration.store();

    sendSetup();
  }

  if(checkAPModeRequest())
  {
    if(pairingOngoing)
      simpleEspConnection.endPairing();

    pairingOngoing = false;
    configurationMode = true;
    startConfigurationAP();
    
    return;    
  }

  if(pairingOngoing)
    return;  
  
  if(configurationMode)
  {
    server.handleClient();
    return;  
  }

  if(gatewayMode)
  {
    handleGatewayLoop();
    return;
  }
  else
  {
    handleESPNowLoop();
  }
  
  
  if(!sleepEnabled)
    return;
  
  if(forceSleep || (lastIntervalTime > 0 && millis() > MAXCONTROLWAIT+lastIntervalTime))
  {
    if(!preparing && !setNewDeviceType && simpleEspConnection.isSendBufferEmpty())
    {      
      if(!avoidSleeping)
      {
        if(atoi(configuration.get("interval")) < 0)    
          gotoInfiniteSleep();
        else
          gotoSleep();
      }
    }
  }  

  if(initReboot && !writeConfiguration)
  {
    ESP.restart();
    delay(500);

    return;
  }  
}

void gotoInfiniteSleep()
{
  int sleepSecs;
  DLN("Up for "+String(millis())+" ms, going down for sleep and hope will not be waked up by myself... \n"); 

  if(!configuration.containsKey("interval"))
  {
    configuration.resetConfiguration();
    ESP.restart();
    delay(500);

    return;
  }

  sleepSecs = atoi(configuration.get("interval"))*(-1);
  if(atoi(configuration.get("sensorpowerpin")) != 99)
  {      
    digitalWrite(atoi(configuration.get("sensorpowerpin")),LOW);          
    pinMode(atoi(configuration.get("sensorpowerpin")), INPUT);      
  }
  
  ESP.deepSleep(sleepSecs * 1000000, RF_NO_CAL);
  
  delay(100);  
}

void gotoSleep() 
{  
  delete dev;  
  int sleepSecs;

  if(strcmp(configuration.get("devicetype"), "UNKNOWN") == 0) // goto sleep just for 5 seconds and flash 2 times
  {
    sleepSecs = 5;
#ifdef LEDPIN
    pinMode(LEDPIN, OUTPUT);

    digitalWrite(LEDPIN, LOW);
    delay(100);
    digitalWrite(LEDPIN, HIGH);
    delay(100);
    digitalWrite(LEDPIN, LOW);
    delay(100);
    digitalWrite(LEDPIN, HIGH);
#endif
  }
  else
  {
    sleepSecs = atoi(configuration.get("interval")) - atoi(configuration.get("preparetime"));
  }

  DLN("Up for "+String(millis())+" ms, going to sleep for "+String(sleepSecs)+" secs... \n"); 

  if(sleepSecs > 0)
  {
    if(atoi(configuration.get("sensorpowerpin")) != 99)
    {      
      digitalWrite(atoi(configuration.get("sensorpowerpin")),LOW);          
      pinMode(atoi(configuration.get("sensorpowerpin")), INPUT);      
    }
    
    ESP.deepSleep(sleepSecs * 1000000, RF_NO_CAL);
  }
  
  delay(100);
}

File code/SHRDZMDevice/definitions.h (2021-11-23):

const static char informationtable_template[] PROGMEM = 
{
"<br>\
Firmware Version : %s-%s<br><br>\
Device Type : %s<br>\
Chip ID : %d<br>\
Gateway Mode : %s<br>\
MQTTTopic Gateway : SHRDZM/%s<br>\
MQTTTopic Device : SHRDZM/%s/%s<br>\
MQTTTopic Sensor : SHRDZM/%s/%s/sensor/<br><br>\
<p>MQTT Connection State : <span id='mqttconnectionstate'>UNKNOWN</span><br>\
Date/Time : <span id='timestamp'>Unknown</span>\
</p><br><br>Last Measurement : <br>\
<textarea readonly style=\"background-color:white;\" id=\"lastmessage\" name=\"lastmessage\" cols=\"65\" rows=\"10\"></textarea><br><br>\
IP : %s<br>\
DNS : %s<br>\
Gateway : %s<br>\
Subnet : %s<br>"
};

const static char settings_template[] PROGMEM = 
{      
"<h1>Settings</h1><p><strong>Configuration</strong><br /><br />\
<form method='post' id='settingsForm'>\
<label>Device Type :\
<select name='devices' onchange='submitDeviceChange(this)'>\
%s\
</select>\
</label>\
<br/><br/>\
%s\
<br/><br/>\
<input type='hidden' id='save' name='save' value='false'/>\
<input type='hidden' id='devicechanged' name='devicechanged' value='false'/>\
<input class='submitbutton' type='submit' onclick='submitForm()' value='Save Configuration!' />\
<script>\
function submitForm()\
{\
document.getElementById('save').value = 'true';\
}\
function submitDeviceChange(f)\
{\
document.getElementById('devicechanged').value = 'true';\
f.form.submit();\
}\
</script>\
</form>"
};

const static char upgrade_template[] PROGMEM = 
{        
"<!DOCTYPE html>\
<html>\
<head>\
</head>\
<body>\
<h1>Upgrade started. SHRDZMDevice will reboot after upgrade.</h1>\
</body>\
</html>"
};

const static char upgradetext_template[] PROGMEM = 
{
"<br/><br/><input type='hidden' id='upgrade' name='upgrade' value='false'/><br/>\
<input class='factoryresetbutton' type='submit' onclick='submitFormUpgrade()' value='OTA Upgrade' />\
<input type='text' id='upgradepath' name='upgradepath' size='35' value='http://shrdzm.pintarweb.net/upgrade.php'>\
<br/>"  
};

const static char handleReboot_template[] PROGMEM = 
{
"<!DOCTYPE html>\
<html>\
<head>\
<meta http-equiv='refresh' content='13; url=/'>\
</head>\
<body>\
<h1>Please wait. Will reboot in 15 seconds...</h1>\
</body>\
</html>"
};

const static char handleGateway_template[] PROGMEM = 
{
"<h1>Gateway</h1><p><strong>Configuration</strong><br /><br />\
WLAN Settings if Device acts as it's own gateway.\
<br/><br/>\
<form method='post'>\
<input type='checkbox' id='wlanenabled' name='wlanenabled' value='1' %s/>\
<input type='hidden' name='wlanenabled' value='0' />\
<div><label for='wlanenabled'>Device should act as it's own gateway</label></div><br/>\
<br/><br/>\
<hr/>\
<div><input type='text' id='ssid' name='ssid' placeholder='SSID' size='50' value='%s'>\
<p><label for='ssid'>SSID</label></p></div><br/>\
<br/>\
<div><input type='password' id='password' name='password' placeholder='Password' size='50' value='%s'>\
<label for='password'>Password</label></div><br/><br/>\
<div><input type='checkbox' onclick='showWLANPassword()'>Show Password\
</div><br/>\
<div><input type='text' id='ip' name='ip' placeholder='XXX.XXX.XXX.XXX' size='50' value='%s'>\
<label for='ip'>Static IP</label></div><br/>\
<br/>\
<div><input type='text' id='dns' name='dns' placeholder='XXX.XXX.XXX.XXX' size='50' value='%s'>\
<label for='ip'>DNS</label></div><br/>\
<br/>\
<div><input type='text' id='gateway' name='gateway' placeholder='XXX.XXX.XXX.XXX' size='50' value='%s'>\
<label for='gateway'>Gateway</label></div><br/>\
<br/>\
<div><input type='text' id='subnet' name='subnet' placeholder='XXX.XXX.XXX.XXX' size='50' value='%s'>\
<label for='gateway'>Subnet</label></div><br/>\
<br/><br/>\
<hr/>\
<br/><br/>\
<input type='checkbox' id='mqttenabled' name='mqttenabled' value='1' %s/>\
<input type='hidden' name='mqttenabled' value='0' />\
<div><label for='mqttenabled'>MQTT Enable (only affected if Device acts as it's on gateway)</label></div><br/>\
<br/><br/>\
<div><input type='text' id='MQTTbroker' name='MQTTbroker' placeholder='MQTT Broker' size='50' value='%s'>\
<label for='MQTTbroker'>MQTT Broker</label></div><br/>\
<br/>\
<div><input type='text' id='MQTTport' name='MQTTport' placeholder='MQTT Port' size='50' value='%s'>\
<label for='MQTTport'>MQTT Port</label></div><br/>\
<br/>\
<div><input type='text' id='MQTTuser' name='MQTTuser' placeholder='MQTT User' size='50' value='%s'>\
<label for='MQTTuser'>MQTT User</label></div><br/>\
<br/>\
<div><input type='text' id='MQTTpassword' name='MQTTpassword' placeholder='MQTT Password' size='50' value='%s'>\
<label for='MQTTpassword'>MQTT Password</label></div><br/>\
<br/><br />\
<input type='checkbox' id='jsonenabled' name='jsonenabled' value='1' %s/>\
<input type='hidden' name='jsonenabled' value='0' />\
<div><label for='jsonenabled'>Send values in JSon format</label></div><br/>\
<br/><br/>\
<input class='submitbutton' type='submit' value='Save Configuration!' />\
<script>\
function showWLANPassword() {\
var x = document.getElementById('password');\
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

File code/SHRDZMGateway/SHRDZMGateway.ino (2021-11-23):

/*
  SHRDZMGateway

  Created 05 Mai 2020
  By Erich O. Pintar
  Modified 28 August 2020
  By Erich O. Pintar

  https://github.com/saghonfly

*/
#include "config/config.h"
#include <ArduinoJson.h>
#include "SimpleEspNowConnection.h"
#include "SetupObject.h"
#include "SerialBufferObject.h"
#include "MQTTBufferObject.h"
#include "StringSplitter.h"
#include <SoftwareSerial.h>

#include <ESP8266WiFi.h>
#include <ESP8266WiFiMulti.h>
#include <ESP8266httpUpdate.h>
#include <ESP8266WebServer.h>

#define TINY_GSM_MODEM_SIM800
#define DEBUG_SHRDZM

#include <TinyGsmClient.h>
#include <PubSubClient.h>

SimpleEspNowConnection simpleEspConnection(SimpleEspNowRole::SERVER);
DynamicJsonDocument configdoc(1024);
//JsonObject configurationDevices  = configdoc.createNestedObject("devices");

typedef struct struct_esp_message {
  char prefix = '.';
  char type;
  long sendTime;  
  uint8_t pc; // packe count
  uint8_t p;  // package  
  uint8_t len;
  char message[200];
  uint16_t checksum;  
} esp_message;

SoftwareSerial SerialAT(14, 12); // RX, TX for SIM800
TinyGsm modem(SerialAT);
TinyGsmClient client(modem);
PubSubClient mqtt(client);

ESP8266WebServer server(80);

String MQTT_TOPIC;
String nodeName;
String localIP;
String inputString;
String clientAddress;
String myAddress;
String SSID;
String password;
String host;
String url;
bool firmwareUpdate = false;
String lastVersionNumber;
String currVersion;
String ver, nam;
uint32_t lastReconnectAttempt = 0;
String deviceName;
bool simEnabled = false;
bool accesspointmodeEnabled = false;
int ap_pin = -1;

ESP8266WiFiMulti WiFiMulti;


String subscribeTopicSet;
String subscribeTopicConfig;
String APName;

SetupObject setupObject;
MQTTBufferObject mqttBufferObject;
SerialBufferObject serialBufferObject;

// AP WebServer
char* getWebsite(char* content)
{  
  int len = strlen(content);
  
  char *temp = (char *) malloc (1400+len);

#ifdef DEBUG
  Serial.println("Handle Root");
  Serial.println("Content len = "+String(len));
#endif

  snprintf(temp, 1400+len,  
"<!DOCTYPE html>\
<html>\
<head>\
<link rel=\"icon\" type=\"image/svg+xml\" href=\"https://shrdzm.pintarweb.net/Logo_min_blue.svg\" sizes=\"any\">\
<style>\
body {\
  font-family: Arial, Helvetica, sans-serif;\
}\
\
hr\
{ \
  display: block;\
  margin-top: 0.5em;\
  margin-bottom: 0.5em;\
  margin-left: auto;\
  margin-right: auto;\
  border-style: inset;\
  border-width: 1px;\
}\
ul \
{\
list-style-type: none;\
  margin: 0;\
  padding: 0;\
  width: 150px;\
  background-color: #f1f1f1;\
  position: fixed;\
  height: 100%;\
  overflow: auto;\
}\
\
li a {\
  display: block;\
  color: #000;\
  padding: 8px 16px;\
  text-decoration: none;\
}\
\
li a.active {\
  background-color: #0080FF;\
  color: white;\
}\
\
li a:hover:not(.active) {\
  background-color: #555;\
  color: white;\
}\
.main {\
  margin-left: 200px;\
  margin-bottom: 30px;\
}\
</style>\
<title>SHRDZMGateway - %s</title>\
</head>\
<body>\
\
<ul>\
  <li>\
    <a class='active' href='#home'>SHRDZMGateway<br/>\
      <font size='2'>%s</font>\
    </a></li>\
  <li><a href='./general'>General</a></li>\
  <li><a href='./settings'>Settings</a></li>\
  <li><a href='./about'>About</a></li>\
  <li><a href='./reboot'>Reboot</a></li>\
  <br/>\
  <li><a href='./deleteconfig'>Delete Config</a></li>\  
  <br/><br/><br/>\
  <li><center>&copy;&nbsp;<font size='2' color='darkgray'>Erich O. Pintar</font></center></li>\  
  <br/><br/>\
</ul>\
\
<div class='main'>\
  %s\
</div>\
</body>\
</html>\
  ", deviceName.c_str(), deviceName.c_str(), content);

  return temp;
}

void handleRoot() 
{
  char * temp = getWebsite("<h1>General</h1>General Information");

  server.send(200, "text/html", temp);

  free(temp);
}
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

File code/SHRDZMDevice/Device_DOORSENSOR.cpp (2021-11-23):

#include "Device_DOORSENSOR.h"   

struct rst_info {
  uint32 reason;
  uint32 exccause;
  uint32 epc1;
  uint32 epc2;
  uint32 epc3;
  uint32 excvaddr;
  uint32 depc;
};   

Device_DOORSENSOR::Device_DOORSENSOR()
{  
  dataAvailable = false;  
  deviceTypeName = "DOORSENSOR";
  m_pConfigurationObject = NULL;    

//  Serial.printf("Constructor Device_DOORSENSOR\n");
}

Device_DOORSENSOR::~Device_DOORSENSOR()
{
  Serial.println("DOORSENSOR Instance deleted");
}

bool Device_DOORSENSOR::setDeviceParameter(JsonObject obj)
{
  DeviceBase::setDeviceParameter(obj);

  if(deviceParameter.containsKey("pin"))
  {
    if(deviceParameter["pin"].as<uint8_t>() != 99)
      pinMode(deviceParameter["pin"].as<uint8_t>(), INPUT_PULLUP);
  }
}

bool Device_DOORSENSOR::initialize()
{
  // create an object
  deviceParameter = doc.to<JsonObject>();
  
  deviceParameter["pin"] = "5";

  return true;
}

SensorData* Device_DOORSENSOR::readParameterTypes()
{
  SensorData *al = new SensorData(1);

  al->di[0].nameI = "state";

  return al;
}

SensorData* Device_DOORSENSOR::readInitialSetupParameter()
{
  SensorData *al = new SensorData(2);

  al->di[0].nameI = "interval";
  al->di[0].valueI = "-30";
  al->di[1].nameI = "preparetime";
  al->di[1].valueI = "0";

  return al;
}
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

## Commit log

2020-01-21 SensorDataExchange added
2020-01-23 Device name added
2020-01-24 SensorGatewayMQTTNot added
2020-02-09 Wiring added
2020-02-10 STL Added
    [ESPWLANGatewayAntennaHolder.stl, ESPWLANGatewayBottom.stl, ESPWLANGatewayTop.stl]
2020-02-16 Sensor Setup added
2020-02-18 Interval set added
    [Case1.skp, Case1.stl]
2020-03-28 Sensor case added
    [Case2-0.skp, Case2.skp, Case2.stl]
2020-04-20 Watersensor Update
    [Holder.skp, Holder.stl, HolderTop_1.skp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]
2020-05-19 BMP280 sensor added
2020-05-19 BME280 sensor added
2020-05-19 FC04 sensor added
2021-01-09 First version of 4th generation
    [Configuration.h]
2021-01-10 Back to 0.3.3
    [Configuration.h]
2021-02-05 Dewpoint added for HTU21 sensor
2021-02-05 Heat Index added for DHT22 and HTU21
2021-02-11 Water BOM added
2021-02-20 Update Wiring
2021-03-07 IM350 Correction
    IM350 was always showing same values in permanent online mode (Integration Style ZERO) due to uninitialited cipher object.
    [Device_IM350.cpp, SHRDZMDevice.ino]
2021-03-20 KiCAD files added
    [DOORSENSOR-B_Cu.gbr, DOORSENSOR-B_Mask.gbr, DOORSENSOR-B_Paste.gbr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]
2021-03-21 Doorsensor PCB added
    [DOORSENSOR - Single.kicad_pcb]
2021-03-21 DOORSENSOR Updated
    [DOORSENSOR - Single.kicad_pcb]
2021-03-23 SDS011 Circuit added
    [SDS011.dsn, SDS011.kicad_pcb, SDS011.sch]
2021-03-25 DOORSENSOR state error added
    [Device_DOORSENSOR.cpp, SHRDZMDevice.ino]
2021-04-04 IM350 Invert Serial added
    [Device_IM350.cpp]
2021-04-07 IM350_AM550_5V Gerber files added
    [IM350_AM550.dsn, IM350_AM550.kicad_pcb, IM350_AM550.sch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]
2021-04-10 Update 3D Models
    [DOORSENSOR.sch, IM350_AM550_5V_SMD.dsn, IM350_AM550_5V_SMD.kicad_pcb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]
2021-04-12 Bootreason added
    [DOORSENSOR_Enhanced.kicad_pcb, IM350_AM550.kicad_pcb]
2021-04-15 DOORSENSOR 9V KiCAD added
    [DOORSENSOR.sch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]
2021-05-05 Website last measurement values added
    [DOORSENSOR_Simple_9V.sch]
2021-05-24 IM350 Wels bug fix
    [Device_IM350.cpp]
2021-05-30 Experimental Cloud added
    [Configuration.h, IM350_AM550_LowPower.kicad_pcb, IM350_AM550_LowPower.sch]
2021-08-01 SmartMeter update
    [Configuration.h]
2021-08-08 Website handleSettings bugfix
    [IM350_AM550_5V.dsn, IM350_AM550_5V.kicad_pcb, IM350_AM550_5V.sch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]
2021-08-12 IM350 Cloud Update bugfix
    [Device_IM350.cpp]
2021-10-06 Smartmeter Energie Steiermark added
    [Gateway.kicad_pcb, Gateway.sch, IM350_AM550_5V_V4.0.dsn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]
2021-10-17 Smartmeter updated
    [IM350_AM550_T210_5V_V5.0.sch]
2021-10-25 Smartmeter IR Head added
    [IR_Schreib_Lesekopf_RS232_Neu.brd, IR_Schreib_Lesekopf_RS232_Neu.kicad_pcb, IR_Schreib_Lesekopf_RS232_Neu.sch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]

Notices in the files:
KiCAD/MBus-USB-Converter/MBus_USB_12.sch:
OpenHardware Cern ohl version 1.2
